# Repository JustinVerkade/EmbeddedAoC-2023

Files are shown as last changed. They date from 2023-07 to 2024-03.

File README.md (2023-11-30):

# Embedded-AoC "Yuki"<br />
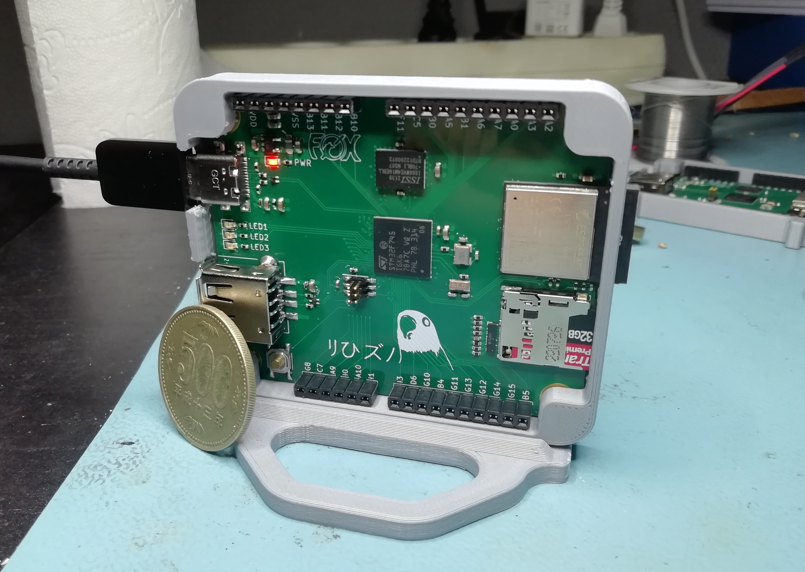
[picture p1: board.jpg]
EmbeddedAoC
<br />

## Todo<br />
-> Add ESP32 bootloader function in vcom user interface for remote programming.<br />
-> Add system check for ESP32.<br />

## Completed<br />
-> Added a malloc/calloc/clrmem functions to allocate memory from the SRAM block.<br />
-> Configured FMC and linker to include the external memory as SRAM block.<br />
-> Added vcom enable variable so the system can respond to being opend as port.<br />
-> Added intermediate usb layer as the transmit function failed when bizzy without feedback.<br />
-> f_debug function to log FatFs problems to vcom interface.<br />
-> Added system check for SD card.<br />
-> Added system check for SRAM memory.<br />
-> Added system structure for executing AoC puzzles.<br />

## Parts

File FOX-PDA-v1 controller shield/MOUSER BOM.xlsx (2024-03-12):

Name: | Description: | Price | Qty | Total | Link
THB001P | Joystick | €1.88 | 1 | €1.88 | https://nl.mouser.com/ProductDetail/CK/THB001P?qs=OlC7AqGiEDlMaVQ%2FEBrivA%3D%3D
150060AS75000 | LEDS 0805 | €0.14 | 3 | €0.42 | https://nl.mouser.com/ProductDetail/Wurth-Elektronik/150060AS75000?qs=d0WKAl%252BL4KbvMBYryeof0Q%3D%3D
CL21A106MQFNNNF | Capacitor 0805 10u | €0.09 | 3 | €0.28 | https://nl.mouser.com/ProductDetail/Samsung-Electro-Mechanics/CL21A106MQFNNNF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
CRCW08055K00JNTA | Resistor 0805 5k | €0.15 | 6 | €0.90 | https://nl.mouser.com/ProductDetail/Vishay-Dale/CRCW08055K00JNTA?qs=ypDtOmddc9yTg%252BhfBkNNHg%3D%3D
68001-206HLF | Header 6p male | €0.45 | 1 | €0.45 | https://nl.mouser.com/ProductDetail/Amphenol-FCI/68001-206HLF?qs=zh4O8xspOuwCLzyjXImWOg%3D%3D
68001-208HLF | Header 8p male | €0.69 | 1 | €0.69 | https://nl.mouser.com/ProductDetail/Amphenol-FCI/68001-208HLF?qs=p7Li5uGGkAoXsNrI4svk2w%3D%3D
68001-210HLF | Header 10p male | €0.67 | 2 | €1.33 | https://nl.mouser.com/ProductDetail/Amphenol-FCI/68001-210HLF?qs=QKvFUfBIyQKW08n2%252BQxlGA%3D%3D
 |  | Total | 17 | €5.96

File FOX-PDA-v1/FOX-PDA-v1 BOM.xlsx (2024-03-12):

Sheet: Sheet1
Name: | Description: | Price | Qty | Total | Link
STM32F745IGK6 | Microcontroller | €19.240 | 1 | €19.24 | https://nl.mouser.com/ProductDetail/STMicroelectronics/STM32F745IGK6?qs=k5OWtXsTJarJliH1%252Bru6hg%3D%3D
IS66WVE4M16EBLL-70BLI | PSRAM 64Mbit | €4.440 | 1 | €4.44 | https://nl.mouser.com/ProductDetail/ISSI/IS66WVE4M16EBLL-70BLI?qs=ULk7ZlyDR4cw9k0cpKJeQQ%3D%3D
ESP32-S2-MINI-1-N4 | ESP32 Wifi module | €2.050 | 1 | €2.05 | https://nl.mouser.com/ProductDetail/Espressif-Systems/ESP32-S2-MINI-1-N4
USB1046-GF-0190-L-B-A | USB-A connector | €0.714 | 1 | €0.71 | https://nl.mouser.com/ProductDetail/GCT/USB1046-GF-0190-L-B-A?qs=KUoIvG%2F9IlbZOJtEsn1unA%3D%3D
USB4110-GF-A | USB-C connector | €1.270 | 1 | €1.27 | https://nl.mouser.com/ProductDetail/GCT/USB4110-GF-A?qs=KUoIvG%2F9IlYiZvIXQjyJeA%3D%3D
MEM2080-00-128-00-A | uSD connector | €1.460 | 1 | €1.46 | https://nl.mouser.com/ProductDetail/GCT/MEM2080-00-128-00-A?qs=vvQtp7zwQdPJXzpf1SnYug%3D%3D
ADP2108AUJZ-3.3-R7 | regulator | €2.260 | 1 | €2.26 | https://nl.mouser.com/ProductDetail/Analog-Devices/ADP2108AUJZ-3.3-R7?qs=WIvQP4zGangwKS4DOjDn0A%3D%3D
TS18-5-25-SL-260-SMT-TR | Reset button | €0.179 | 1 | €0.18 | https://nl.mouser.com/ProductDetail/CUI-Devices/TS18-5-25-SL-260-SMT-TR?qs=tlsG%2FOw5FFh0yS4gYnfcwg%3D%3D
ECS-160-7-33B-CKL-TR | 16MHz crystal | €0.479 | 1 | €0.48 | https://nl.mouser.com/ProductDetail/ECS/ECS-160-7-33B-CKL-TR?qs=wd5RIQLrsJhEy%252BtlnvJYvQ%3D%3D
ECS-.327-12.5-34B-TR | 32.- KHz crystal | €0.649 | 1 | €0.65 | https://nl.mouser.com/ProductDetail/ECS/ECS-.327-12.5-34B-TR?qs=xCP1SmiXvZHPyAjhnmNtEw%3D%3D
LQM21PN1R0MC0D | Power inductor buck converter | €0.216 | 1 | €0.22 | https://nl.mouser.com/ProductDetail/Murata-Electronics/LQM21PN1R0MC0D?qs=%2F%252BYoplLUB5gbQdB9sWu6pw%3D%3D
TPD2EUSB30ADRTR | USB ESD diodes | €0.517 | 2 | €1.03 | https://nl.mouser.com/ProductDetail/Texas-Instruments/TPD2EUSB30ADRTR?qs=O1HRStiETCgOfMa6oTfOlg%3D%3D
ESD8708MUTAG | uSD ESD diodes | €0.639 | 1 | €0.64 | https://nl.mouser.com/ProductDetail/onsemi/ESD8708MUTAG?qs=%252B6g0mu59x7J1h3T%252BrbDk%252Bw%3D%3D
ESD9L5.0ST5G | 50V ESD diodes | €0.348 | 2 | €0.70 | https://nl.mouser.com/ProductDetail/onsemi/ESD9L5.0ST5G?qs=lq5%252BOP7PS0%252BtbEEODUxZiA%3D%3D
SLW-108-01-T-S | IO header 8p | €1.230 | 1 | €1.23 | https://nl.mouser.com/ProductDetail/Samtec/SLW-108-01-T-S?qs=rU5fayqh%252BE3vM7KKJPKLBQ%3D%3D
SLW-110-01-T-S | IO header 10p | €1.160 | 2 | €2.32 | https://nl.mouser.com/ProductDetail/Samtec/SLW-110-01-T-S?qs=WqbWUrltBn0VpUHXVPrl6A%3D%3D
SLW-106-01-T-S | IO header 6p | €0.846 | 1 | €0.85 | https://nl.mouser.com/ProductDetail/Samtec/SLW-106-01-T-S?qs=92ilVni64gwgeQzrY9annQ%3D%3D
20021121-00006T4LF | Programming header | €0.564 | 1 | €0.56 | https://nl.mouser.com/ProductDetail/Amphenol-FCI/20021121-00006T4LF?qs=oJs1R%252BxK6kTRYpFukouk8Q%3D%3D
150060AS75000 | LEDS 0805 | €0.141 | 4 | €0.56 | https://nl.mouser.com/ProductDetail/Wurth-Elektronik/150060AS75000?qs=d0WKAl%252BL4KbvMBYryeof0Q%3D%3D
MMZ1005S121HT000 | Ferrite bead | €0.094 | 1 | €0.09 | https://nl.mouser.com/ProductDetail/TDK/MMZ1005S121HT000?qs=1mbolxNpo8cEy9%252BGeuXdTw%3D%3D
CRCW040222R0JNEDC | Resistor 0402 22R | €0.094 | 4 | €0.38 | https://nl.mouser.com/ProductDetail/Vishay-Dale/CRCW040222R0JNEDC?qs=E3Y5ESvWgWOe0pjbCFgU3w%3D%3D
CR0402-FX-2201GLF | Resistor 0402 2.2K | €0.094 | 3 | €0.28 | https://nl.mouser.com/ProductDetail/Bourns/CR0402-FX-2201GLF?qs=JflQ4L8so%2FvNNp%252Bb%2FjYwIg%3D%3D
RT0402FRD0710KL | Resistor 0402 10K | €0.127 | 10 | €1.27 | https://nl.mouser.com/ProductDetail/YAGEO/RT0402FRD0710KL?qs=9h0bZHM%2F3zLluUCJgNukFQ%3D%3D
CRCW040247R0FKEDC | Resistor 0402 47R | €0.094 | 2 | €0.19 | https://nl.mouser.com/ProductDetail/Vishay-Dale/CRCW040247R0FKEDC?qs=E3Y5ESvWgWOUCyfYkhtspA%3D%3D
RT0402FRD071KL | Resistor 0402 1K | €0.160 | 4 | €0.64 | https://nl.mouser.com/ProductDetail/YAGEO/RT0402FRD071KL?qs=ABvmyp11KkjmRlIyrfVQ%252BQ%3D%3D
AC0402JR-075K1L | Resistor 0402 5.1K | €0.094 | 2 | €0.19 | https://nl.mouser.com/ProductDetail/YAGEO/AC0402JR-075K1L?qs=ygRr%2Ftkhtev1AbJgasJMAQ%3D%3D
04026D104KAT2A | Capacitor 0402 100n | €0.010 | 21 | €0.21 | https://nl.mouser.com/ProductDetail/Kyocera-AVX/04026D104KAT2A?qs=LLG2yGGJ5NhILwMziGI8Xg%3D%3D
CL10A225KO8NNNC | Capacitor 0603 2.2u | €0.094 | 9 | €0.85 | https://nl.mouser.com/ProductDetail/Samsung-Electro-Mechanics/CL10A225KO8NNNC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
GRM153R60J225ME95D | Capacitor 0402 2.2u | €0.094 | 2 | €0.19 | https://nl.mouser.com/ProductDetail/Murata-Electronics/GRM153R60J225ME95D?qs=bR4DfHEEY0uHJr0etQOHow%3D%3D
GRM1555C1H100JA01J | Capacitor 0402 10p | €0.094 | 2 | €0.19 | https://nl.mouser.com/ProductDetail/Murata-Electronics/GRM1555C1H100JA01J?qs=ouTquLLW2S5kS%252BYeQbW79A%3D%3D
GRM1555C1H180JA01D | Capacitor 0402 18p | €0.094 | 2 | €0.19 | https://nl.mouser.com/ProductDetail/Murata-Electronics/GRM1555C1H180JA01D?qs=mRkWMvdT7ZKEkI5QPHEfww%3D%3D
06036D475KAT4A | Capacitor 0603 4.7u | €0.122 | 1 | €0.12 | https://nl.mouser.com/ProductDetail/KYOCERA-AVX/06036D475KAT4A?qs=Q5Oar%2FnnWZYQ5N3tKG3HJg%3D%3D
06036D106MAT2A | Capacitor 0603 10u | €0.169 | 1 | €0.17 | https://nl.mouser.com/ProductDetail/Kyocera-AVX/06036D106MAT2A?qs=SnLCPPi%2FUkQWQ97wPZ%2F8XA%3D%3D
 |  | Total | 89 | €45.80
Additional parts
Name: | Description: | Price | Qty | Total | Link
20021311-00006T4LF | Programming header host | €0.686 | 1 | €0.69 | https://nl.mouser.com/ProductDetail/Amphenol-FCI/20021311-00006T4LF?qs=oJs1R%252BxK6kSLec%2FNAKmHQA%3D%3D
10129378-906001BLF | Programming header target | €0.160 | 1 | €0.16 | https://nl.mouser.com/ProductDetail/Amphenol-FCI/10129378-906001BLF?qs=0lQeLiL1qybdgsDy2F9d0g%3D%3D

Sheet: Sheet3
Name: | Description: | Price | Qty | Total | Link
STM32F745IGK6 | Microcontroller | €19.24 | 5 | €96.20 | https://nl.mouser.com/ProductDetail/STMicroelectronics/STM32F745IGK6?qs=k5OWtXsTJarJliH1%252Bru6hg%3D%3D
IS66WVE4M16EBLL-70BLI | PSRAM 64Mbit | €4.44 | 5 | €22.20 | https://nl.mouser.com/ProductDetail/ISSI/IS66WVE4M16EBLL-70BLI?qs=ULk7ZlyDR4cw9k0cpKJeQQ%3D%3D
ESP32-S2-MINI-1-N4 | ESP32 Wifi module | €2.05 | 5 | €10.25 | https://nl.mouser.com/ProductDetail/Espressif-Systems/ESP32-S2-MINI-1-N4
USB1046-GF-0190-L-B-A | USB-A connector | €0.71 | 5 | €3.57 | https://nl.mouser.com/ProductDetail/GCT/USB1046-GF-0190-L-B-A?qs=KUoIvG%2F9IlbZOJtEsn1unA%3D%3D
USB4110-GF-A | USB-C connector | €1.27 | 5 | €6.35 | https://nl.mouser.com/ProductDetail/GCT/USB4110-GF-A?qs=KUoIvG%2F9IlYiZvIXQjyJeA%3D%3D
MEM2080-00-128-00-A | uSD connector | €1.46 | 5 | €7.30 | https://nl.mouser.com/ProductDetail/GCT/MEM2080-00-128-00-A?qs=vvQtp7zwQdPJXzpf1SnYug%3D%3D
ADP2108AUJZ-3.3-R7 | regulator | €2.26 | 5 | €11.30 | https://nl.mouser.com/ProductDetail/Analog-Devices/ADP2108AUJZ-3.3-R7?qs=WIvQP4zGangwKS4DOjDn0A%3D%3D
TS18-5-25-SL-260-SMT-TR | Reset button | €0.18 | 5 | €0.90 | https://nl.mouser.com/ProductDetail/CUI-Devices/TS18-5-25-SL-260-SMT-TR?qs=tlsG%2FOw5FFh0yS4gYnfcwg%3D%3D
ECS-160-7-33B-CKL-TR | 16MHz crystal | €0.52 | 5 | €2.58 | https://nl.mouser.com/ProductDetail/ECS/ECS-160-7-33B-CKL-TR?qs=wd5RIQLrsJhEy%252BtlnvJYvQ%3D%3D
ECS-.327-12.5-34B-TR | 32.- KHz crystal | €0.65 | 5 | €3.25 | https://nl.mouser.com/ProductDetail/ECS/ECS-.327-12.5-34B-TR?qs=xCP1SmiXvZHPyAjhnmNtEw%3D%3D
LQM21PN1R0MC0D | Power inductor buck converter | €0.22 | 5 | €1.08 | https://nl.mouser.com/ProductDetail/Murata-Electronics/LQM21PN1R0MC0D?qs=%2F%252BYoplLUB5gbQdB9sWu6pw%3D%3D
TPD2EUSB30ADRTR | USB ESD diodes | €0.52 | 10 | €5.17 | https://nl.mouser.com/ProductDetail/Texas-Instruments/TPD2EUSB30ADRTR?qs=O1HRStiETCgOfMa6oTfOlg%3D%3D
ESD8708MUTAG | uSD ESD diodes | €0.64 | 5 | €3.20 | https://nl.mouser.com/ProductDetail/onsemi/ESD8708MUTAG?qs=%252B6g0mu59x7J1h3T%252BrbDk%252Bw%3D%3D
ESD9L5.0ST5G | 50V ESD diodes | €0.35 | 10 | €3.48 | https://nl.mouser.com/ProductDetail/onsemi/ESD9L5.0ST5G?qs=lq5%252BOP7PS0%252BtbEEODUxZiA%3D%3D
SLW-108-01-T-S | IO header 8p | €1.23 | 5 | €6.15 | https://nl.mouser.com/ProductDetail/Samtec/SLW-108-01-T-S?qs=rU5fayqh%252BE3vM7KKJPKLBQ%3D%3D
SLW-110-01-T-S | IO header 10p | €1.16 | 10 | €11.60 | https://nl.mouser.com/ProductDetail/Samtec/SLW-110-01-T-S?qs=WqbWUrltBn0VpUHXVPrl6A%3D%3D
SLW-106-01-T-S | IO header 6p | €0.85 | 5 | €4.23 | https://nl.mouser.com/ProductDetail/Samtec/SLW-106-01-T-S?qs=92ilVni64gwgeQzrY9annQ%3D%3D
20021121-00006T4LF | Programming header | €0.56 | 5 | €2.82 | https://nl.mouser.com/ProductDetail/Amphenol-FCI/20021121-00006T4LF?qs=oJs1R%252BxK6kTRYpFukouk8Q%3D%3D
150060AS75000 | LEDS 0805 | €0.14 | 20 | €2.82 | https://nl.mouser.com/ProductDetail/Wurth-Elektronik/150060AS75000?qs=d0WKAl%252BL4KbvMBYryeof0Q%3D%3D
MMZ1005S121HT000 | Ferrite bead | €0.09 | 5 | €0.00 | https://nl.mouser.com/ProductDetail/TDK/MMZ1005S121HT000?qs=1mbolxNpo8cEy9%252BGeuXdTw%3D%3D
CRCW040222R0JNEDC | Resistor 0402 22R | €0.09 | 20 | €1.88 | https://nl.mouser.com/ProductDetail/Vishay-Dale/CRCW040222R0JNEDC?qs=E3Y5ESvWgWOe0pjbCFgU3w%3D%3D
CR0402-FX-2201GLF | Resistor 0402 2.2K | €0.09 | 15 | €1.41 | https://nl.mouser.com/ProductDetail/Bourns/CR0402-FX-2201GLF?qs=JflQ4L8so%2FvNNp%252Bb%2FjYwIg%3D%3D
RT0402FRD0710KL | Resistor 0402 10K | €0.09 | 50 | €4.70 | https://nl.mouser.com/ProductDetail/YAGEO/RT0402FRD0710KL?qs=9h0bZHM%2F3zLluUCJgNukFQ%3D%3D
CRCW040247R0FKEDC | Resistor 0402 47R | €0.09 | 10 | €0.94 | https://nl.mouser.com/ProductDetail/Vishay-Dale/CRCW040247R0FKEDC?qs=E3Y5ESvWgWOUCyfYkhtspA%3D%3D
RT0402FRD071KL | Resistor 0402 1K | €0.09 | 20 | €1.88 | https://nl.mouser.com/ProductDetail/YAGEO/RT0402FRD071KL?qs=ABvmyp11KkjmRlIyrfVQ%252BQ%3D%3D
AC0402JR-075K1L | Resistor 0402 5.1K | €0.09 | 10 | €0.94 | https://nl.mouser.com/ProductDetail/YAGEO/AC0402JR-075K1L?qs=ygRr%2Ftkhtev1AbJgasJMAQ%3D%3D
04026D104KAT2A | Capacitor 0402 100n | €0.09 | 105 | €9.87 | https://nl.mouser.com/ProductDetail/Kyocera-AVX/04026D104KAT2A?qs=LLG2yGGJ5NhILwMziGI8Xg%3D%3D
CL10A225KO8NNNC | Capacitor 0603 2.2u | €0.09 | 45 | €4.23 | https://nl.mouser.com/ProductDetail/Samsung-Electro-Mechanics/CL10A225KO8NNNC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
GRM153R60J225ME95D | Capacitor 0402 2.2u | €0.09 | 10 | €0.94 | https://nl.mouser.com/ProductDetail/Murata-Electronics/GRM153R60J225ME95D?qs=bR4DfHEEY0uHJr0etQOHow%3D%3D
GRM1555C1H100JA01J | Capacitor 0402 10p | €0.09 | 10 | €0.94 | https://nl.mouser.com/ProductDetail/Murata-Electronics/GRM1555C1H100JA01J?qs=ouTquLLW2S5kS%252BYeQbW79A%3D%3D
GRM1555C1H180JA01D | Capacitor 0402 18p | €0.09 | 10 | €0.94 | https://nl.mouser.com/ProductDetail/Murata-Electronics/GRM1555C1H180JA01D?qs=mRkWMvdT7ZKEkI5QPHEfww%3D%3D
06036D475KAT4A | Capacitor 0603 4.7u | €0.12 | 5 | €0.61 | https://nl.mouser.com/ProductDetail/KYOCERA-AVX/06036D475KAT4A?qs=Q5Oar%2FnnWZYQ5N3tKG3HJg%3D%3D
06036D106MAT2A | Capacitor 0603 10u | €0.17 | 5 | €0.85 | https://nl.mouser.com/ProductDetail/Kyocera-AVX/06036D106MAT2A?qs=SnLCPPi%2FUkQWQ97wPZ%2F8XA%3D%3D
 |  | Total | 445 | €233.72

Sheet: Sheet2
STM32F745IGK6 | 1
IS66WVE4M16EBLL-70BLI | 1
ESP32-S2-MINI-1-N4 | 1
USB1046-GF-0190-L-B-A | 1
USB4110-GF-A | 1
MEM2080-00-128-00-A | 1
ADP2108AUJZ-3.3-R7 | 1
TS18-5-25-SL-260-SMT-TR | 1
ECS-160-7-33B-CKL-TR | 1
ECS-.327-12.5-34B-TR | 1
LQM21PN1R0MC0D | 1
TPD2EUSB30ADRTR | 2
ESD8708MUTAG | 1
ESD9L5.0ST5G | 2
SLW-108-01-T-S | 1
SLW-110-01-T-S | 2
SLW-106-01-T-S | 1
20021121-00006T4LF | 1
150060AS75000 | 4
MMZ1005S121HT000 | 1
CRCW040222R0JNEDC | 4
CR0402-FX-2201GLF | 3
RT0402FRD0710KL | 10
CRCW040247R0FKEDC | 2
RT0402FRD071KL | 4
AC0402JR-075K1L | 2
04026D104KAT2A | 21
CL10A225KO8NNNC | 9
GRM153R60J225ME95D | 2
GRM1555C1H100JA01J | 2
GRM1555C1H180JA01D | 2
06036D475KAT4A | 1
06036D106MAT2A | 1

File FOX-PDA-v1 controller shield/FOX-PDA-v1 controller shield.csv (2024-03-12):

Source: | C:\Users\J.Verkade\OneDrive\KiCad\Projects\FOX-PDA-v1 controller shield\FOX-PDA-v1 controller shield\FOX-PDA-v1 controller shield.kicad_sch
Date: | 21-6-2023 20:30:07
Tool: | Eeschema (6.0.10)
Generator: | C:\Program Files\KiCad\6.0\bin\scripting\plugins/bom_csv_grouped_by_value_with_fp.py
Component Count: | 21
Ref | Qnty | Value | Cmp name | Footprint | Description | Vendor
C1, C2, C3, | 3 | 10u | C_Small | Capacitor_SMD:C_0805_2012Metric | Unpolarized capacitor, small symbol
H1, H2, H3, H4, | 4 | MountingHole_Pad | MountingHole_Pad | MountingHole:MountingHole_3.2mm_M3_Pad_Via | Mounting Hole with connection
J1, | 1 | SLW-108-01-T-S | SLW-108-01-T-S | SamacSys_Parts:SLW-108-01-X-S | 8 Position, .100&quot; Tiger Buy&trade; Low Profile Socket Strip, Single-Row
J2, J3, | 2 | SLW-110-01-T-S | SLW-110-01-T-S | SamacSys_Parts:SLW-110-01-X-S | 10 Position, .100&quot; Tiger Buy&trade; Low Profile Socket Strip, Single-Row
J4, | 1 | SLW-106-01-T-S | SLW-106-01-T-S | SamacSys_Parts:SLW-106-01-X-S | 6 Position, .100&quot; Tiger Buy&trade; Low Profile Socket Strip, Single-Row
LED1, LED2, LED3, | 3 | 150060AS75000 | 150060AS75000 | SamacSys_Parts:LEDC1608X80N | 2.4 V Amber LED 1608 (0603) SMD, Wurth Elektronik WL-SMCW 150060AS75000
R1, R2, R3, R4, R5, R6, | 6 | 5k | R_Small | Resistor_SMD:R_0805_2012Metric | Resistor, small symbol
S1, | 1 | THB001P | THB001P | SamacSys_Parts:THB001P | THUMBSTICK, 0.05A, 12VDC, 2 AXIS, PCB; No. of Axes:2; Track Resistance:10kohm; Supply Voltage Max:-; No. of Switch Positions:-; Contact Current AC Max:-; Contact Voltage AC Max:50V; Rotation Electrical Angle:36

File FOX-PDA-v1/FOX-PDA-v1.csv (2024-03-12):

Source: | C:\Users\J.Verkade\OneDrive\KiCad\Projects\FOX-PDA-v1\FOX-PDA-v1\FOX-PDA-v1.kicad_sch
Date: | 21-6-2023 20:10:43
Tool: | Eeschema (6.0.10)
Generator: | C:\Program Files\KiCad\6.0\bin\scripting\plugins/bom_csv_grouped_by_value_with_fp.py
Component Count: | 93
Ref | Qnty | Value | Cmp name | Footprint | Description | Vendor
C1, C2, C3, C4, C5, C6, C7, C8, C9, C10, C13, C14, C15, C16, C17, C21, C28, C29, C30, C35, C38, | 21 | 100n | C_Small | Capacitor_SMD:C_0402_1005Metric | Unpolarized capacitor, small symbol
C18, C19, | 2 | 2.2u | C_Small | Capacitor_SMD:C_0402_1005Metric | Unpolarized capacitor, small symbol
C20, C22, C23, C24, C25, C26, C27, C36, C37, | 9 | 2.2u | C_Small | Capacitor_SMD:C_0603_1608Metric | Unpolarized capacitor, small symbol
C31, C32, | 2 | 10p | C_Small | Capacitor_SMD:C_0402_1005Metric | Unpolarized capacitor, small symbol
C33, C34, | 2 | 18p | C_Small | Capacitor_SMD:C_0402_1005Metric | Unpolarized capacitor, small symbol
C39, | 1 | 4.7u | C_Small | Capacitor_SMD:C_0603_1608Metric | Unpolarized capacitor, small symbol
C40, | 1 | 10u | C_Small | Capacitor_SMD:C_0603_1608Metric | Unpolarized capacitor, small symbol
D1, | 1 | ESD8708MUTAG | ESD8708MUTAG | SamacSys_Parts:ESD8708MUTAG | ESD Suppressors / TVS Diodes 8 CHANNEL, 3.3 V UNIDIREC
D2, D3, | 2 | ESD9101P2T5G | ESD9101P2T5G | SamacSys_Parts:SODFL1006X40N | Low Capacitance ESD Protection Diodes for High Speed Data Lines
FB1, | 1 | MMZ1005S121HT000 | MMZ1005S121HT000 | SamacSys_Parts:BEADC1005X55N | Ferrite Beads 0402 120ohms 25% General Signal Line
H1, H2, H3, H4, | 4 | MountingHole_Pad | MountingHole_Pad | MountingHole:MountingHole_3.2mm_M3_Pad_Via | Mounting Hole with connection
IC1, | 1 | STM32F745IGK6 | STM32F745IGK6 | SamacSys_Parts:BGA201C65P15X15_1000X1000X60 | High-performance and DSP with FPU, Arm Cortex-M7 MCU with 1 Mbyte of Flash memory, 216 MHz CPU, Art Accelerator, L1 cache, SDRAM
IC2, | 1 | IS66WVE4M16EBLL-70BLI | IS66WVE4M16EBLL-70BLI | SamacSys_Parts:BGA48C75P6X8_600X800X120 | SRAM 64Mb,Pseudo SRAM,Asynch/Page, 4M x 16,70ns,VDD 2.7V 3.6V, VDDQ 2.7V 3.6V,48 Ball BGA (6x8 mm), RoHS
IC3, | 1 | ESP32-S2-MINI-1-N4 | ESP32-S2-MINI-1-N4 | SamacSys_Parts:ESP32S2MINI1N4 | SMD MODULE W/PCB ANTENNA
IC4, IC5, | 2 | TPD2EUSB30ADRTR | TPD2EUSB30ADRTR | SamacSys_Parts:SOT35P100X50-3N | 2-Channel ESD/Surge Solution for High-Speed Low-Voltage Interface
IC6, | 1 | ADP2108AUJZ-3.3-R7 | ADP2108AUJZ-3.3-R7 | SamacSys_Parts:SOT95P280X100-5N | DC-DC 3.3V 600mA 3MHz Step-Down TSOT5 Analog Devices ADP2108AUJZ-3.3-R7, Single Linear Voltage Regulator, 600mA 3.3 V, +/-2 %, +/-2.5 %, 5-Pin TSOT
J1, | 1 | USB1046-GF-0190-L-B-A | USB1046-GF-0190-L-B-A | SamacSys_Parts:USB1046GF0190LBA | USB Connectors USB A Skt, Top Mount, SMT, R/A, GF, Black, With 1.9mm shell stake, T&R
J2, | 1 | USB4110-GF-A | USB4110-GF-A | SamacSys_Parts:USB4110GFA | CONN USB 2.0 TYPE-C R/A SMT
J3, | 1 | SLW-108-01-T-S | SLW-108-01-T-S | SamacSys_Parts:SLW-108-01-X-S | 8 Position, .100&quot; Tiger Buy&trade; Low Profile Socket Strip, Single-Row
J4, | 1 | 20021121-00006T4LF | 20021121-00006T4LF | SamacSys_Parts:HUSSP6W41P127_2X3_381X343X440P | Minitek127, Board to Board connector, Unshrouded vertical header, Surface Mount, Double Row, 6Positions, 1.27mm (0.5inch) pitch.
J5, J6, | 2 | SLW-110-01-T-S | SLW-110-01-T-S | SamacSys_Parts:SLW-110-01-X-S | 10 Position, .100&quot; Tiger Buy&trade; Low Profile Socket Strip, Single-Row
J7, | 1 | SLW-106-01-T-S | SLW-106-01-T-S | SamacSys_Parts:SLW-106-01-X-S | 6 Position, .100&quot; Tiger Buy&trade; Low Profile Socket Strip, Single-Row
J8, | 1 | MEM2080-00-128-00-A | MEM2080-00-128-00-A | SamacSys_Parts:MEM20800012800A | Memory Card Connectors Micro SD, Push Push, SMT, Card Entry Normal, 1.28 mm profile
L1, | 1 | LQM21PN1R0MC0D | LQM21PN1R0MC0D | SamacSys_Parts:LQM21PN1R0MC0D | LQM21PN_C0 Series Inductor 1.0uH +/-20% 0805 (2012)
LED1, LED2, LED3, LED4, | 4 | 150060AS75000 | 150060AS75000 | SamacSys_Parts:LEDC1608X80N | 2.4 V Amber LED 1608 (0603) SMD, Wurth Elektronik WL-SMCW 150060AS75000
R1, R2, R3, R4, | 4 | 22 | R_Small | Resistor_SMD:R_0402_1005Metric | Resistor, small symbol
R5, R6, | 2 | 5K1 | R_Small | Resistor_SMD:R_0402_1005Metric | Resistor, small symbol
R7, R10, R11, | 3 | 2.2k | R_Small | Resistor_SMD:R_0402_1005Metric | Resistor, small symbol
R8, R9, R12, R13, R14, R15, R16, R17, R18, R19, | 10 | 10k | R_Small | Resistor_SMD:R_0402_1005Metric | Resistor, small symbol
R20, R21, | 2 | 47 | R_Small | Resistor_SMD:R_0402_1005Metric | Resistor, small symbol
R22, R23, R24, R25, | 4 | 1k | R_Small | Resistor_SMD:R_0402_1005Metric | Resistor, small symbol
S1, | 1 | TS18-5-25-SL-260-SMT-TR | TS18-5-25-SL-260-SMT-TR | SamacSys_Parts:TS18525SL260SMTTR | TACTILE SWITCH 5 X 5 MM, 2.5 MM ACTUATOR HEIGHT 0.05A @ 12VDC Surface Mount -30C ~ 80C
Y1, | 1 | ECS-160-7-33B-CKL-TR | ECS-160-7-33B-CKL-TR | SamacSys_Parts:ECS160733BCKLTR | CRYSTAL 16MHZ 7PF SMD
Y2, | 1 | ECS-.327-12.5-34S-TR9 | ECS-.327-12.5-34S-TR9 | SamacSys_Parts:ECS32712534STR9 | Crystals 32.768 KHz 12.5 pF +/-20 ppm ECX-34S -40 - +125C 3215 RoHS Compliant

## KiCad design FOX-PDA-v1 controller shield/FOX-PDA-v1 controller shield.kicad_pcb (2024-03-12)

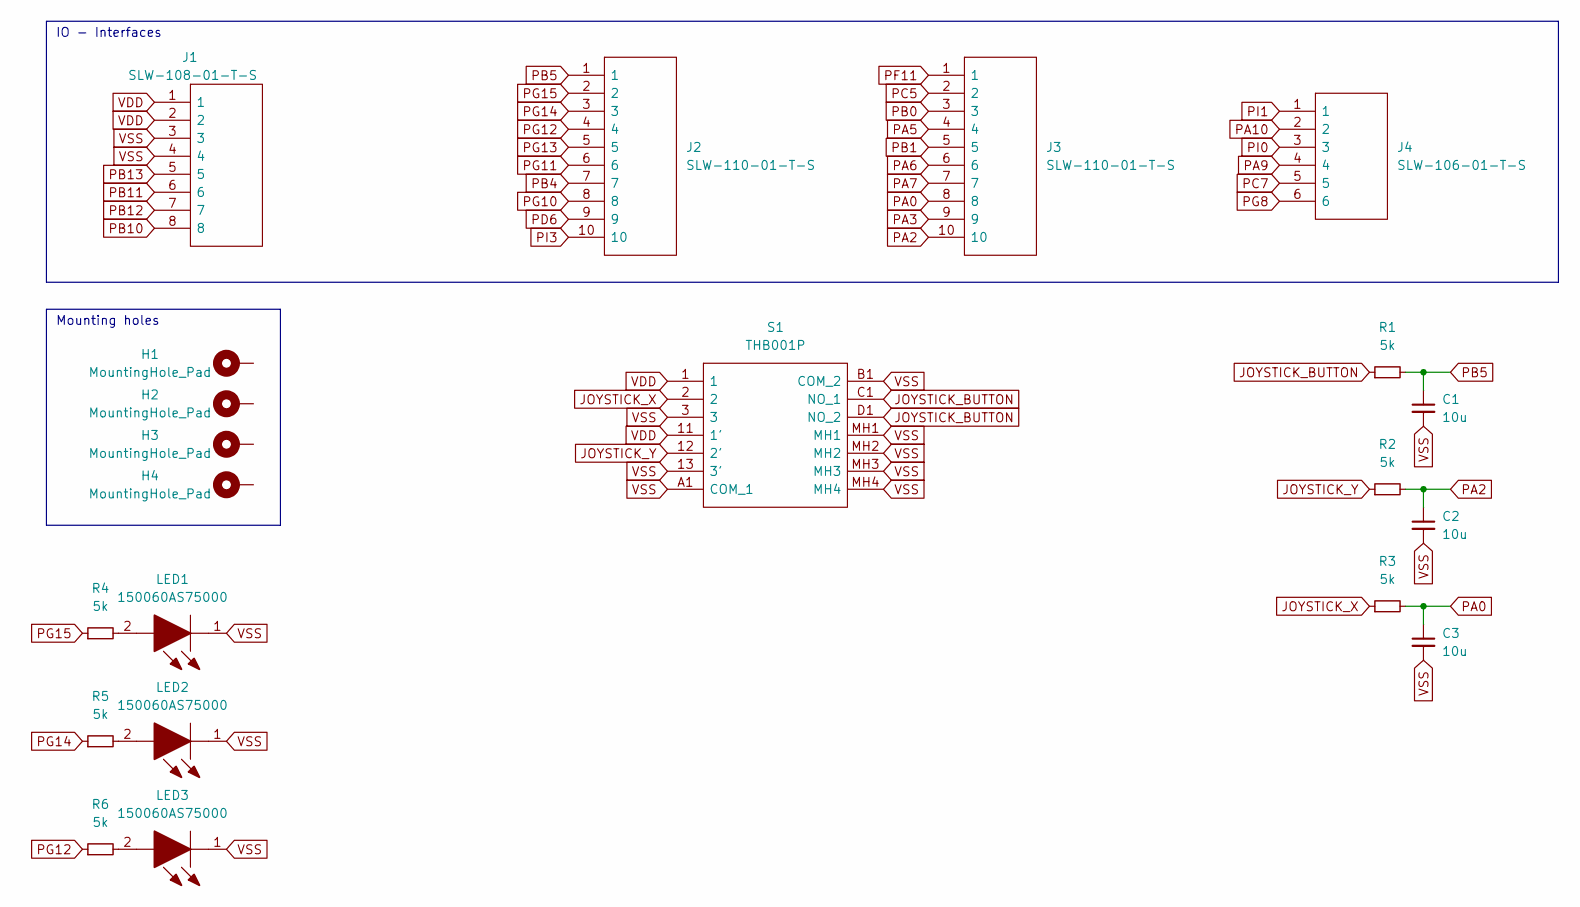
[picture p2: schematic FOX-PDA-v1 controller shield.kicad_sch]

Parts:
C1, C2, C3: 10u; C_0805_2012Metric
H1, H2, H3, H4: MountingHole_Pad; MountingHole_3.2mm_M3_Pad_Via
J1: SLW-108-01-T-S; SLW-108-01-X-S; Mouser Part Number 200-SLW10801TS
J2, J3: SLW-110-01-T-S; SLW-110-01-X-S; Mouser Part Number 200-SLW11001TS
J4: SLW-106-01-T-S; SLW-106-01-X-S; Mouser Part Number 200-SLW10601TS
LED1, LED2, LED3: 150060AS75000; LEDC1608X80N; Mouser Part Number 710-150060AS75000
R1, R2, R3, R4, R5, R6: 5k; R_0805_2012Metric
S1: THB001P; Mouser Part Number 611-THB001P

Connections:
JOYSTICK_BUTTON: R1.1, S1.C1 (NO_1), S1.D1 (NO_2)
JOYSTICK_X: R3.1, S1.2
JOYSTICK_Y: R2.1, S1.12 (2')
unnamed: LED1.2, R4.2
unnamed: LED2.2, R5.2
unnamed: LED3.2, R6.2
PA0: C3.1, J3.8, R3.2
PA2: C2.1, J3.10, R2.2
PA3: J3.9
PA5: J3.4
PA6: J3.6
PA7: J3.7
PA9: J4.4
PA10: J4.2
PB0: J3.3
PB1: J3.5
PB4: J2.7
PB5: C1.1, J2.1, R1.2
PB10: J1.8
PB11: J1.6
PB12: J1.7
PB13: J1.5
PC5: J3.2
PC7: J4.5
PD6: J2.9
PF11: J3.1
PG8: J4.6
PG10: J2.8
PG11: J2.6
PG12: J2.4, R6.1
PG13: J2.5
PG14: J2.3, R5.1
PG15: J2.2, R4.1
PI0: J4.3
PI1: J4.1
PI3: J2.10
VDD: J1.1, J1.2, S1.1, S1.11 (1')
VSS: C1.2, C2.2, C3.2, J1.3, J1.4, LED1.1, LED2.1, LED3.1, S1.3, S1.13 (3'), S1.A1 (COM_1), S1.B1 (COM_2), S1.MH1, S1.MH2, S1.MH3, S1.MH4

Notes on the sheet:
IO - Interfaces
Mounting holes

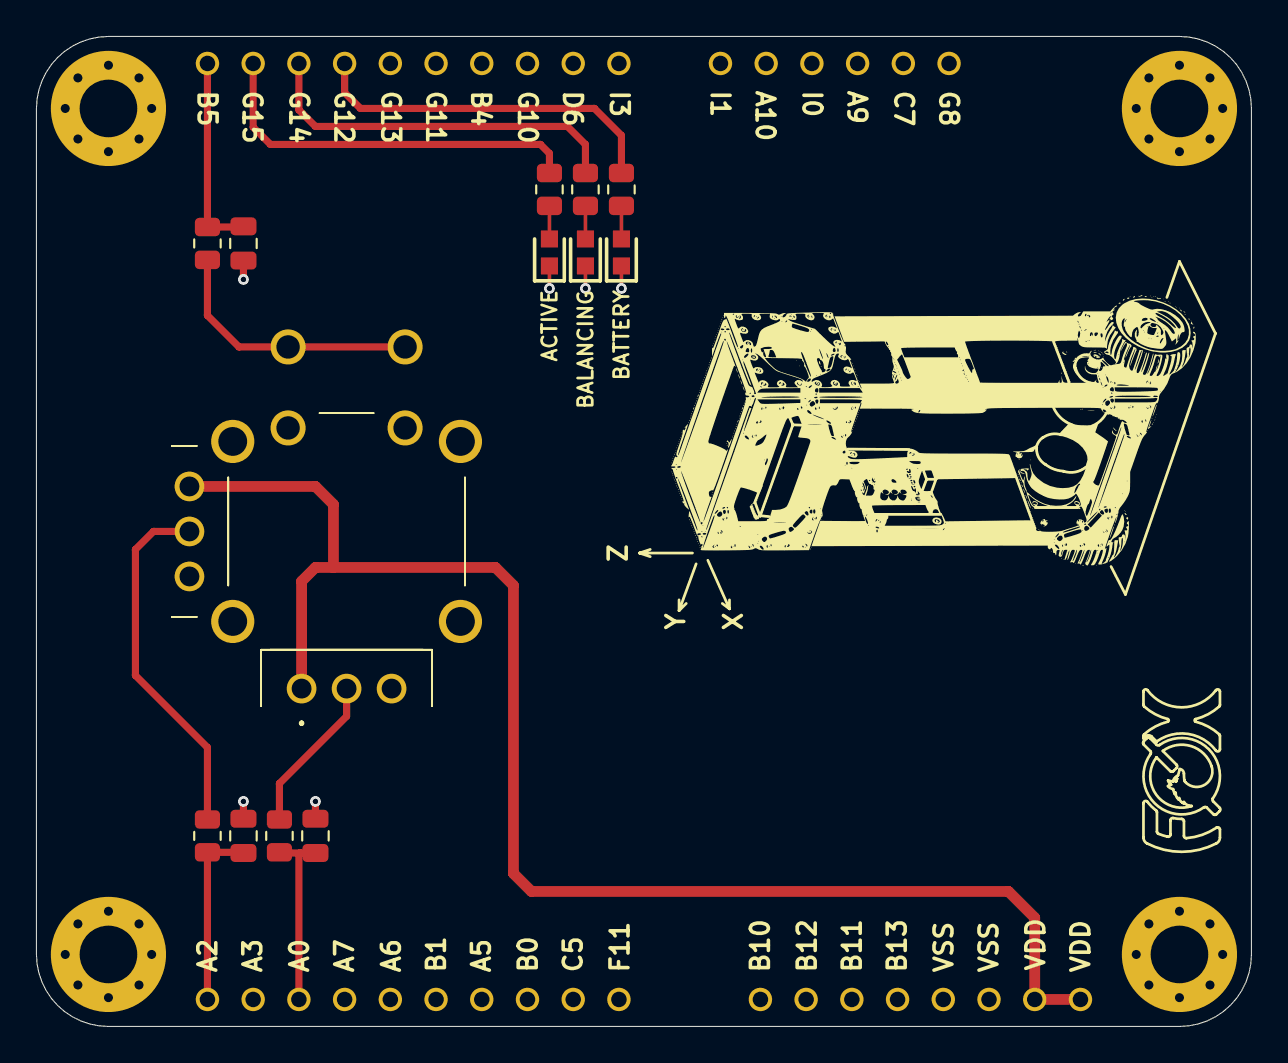
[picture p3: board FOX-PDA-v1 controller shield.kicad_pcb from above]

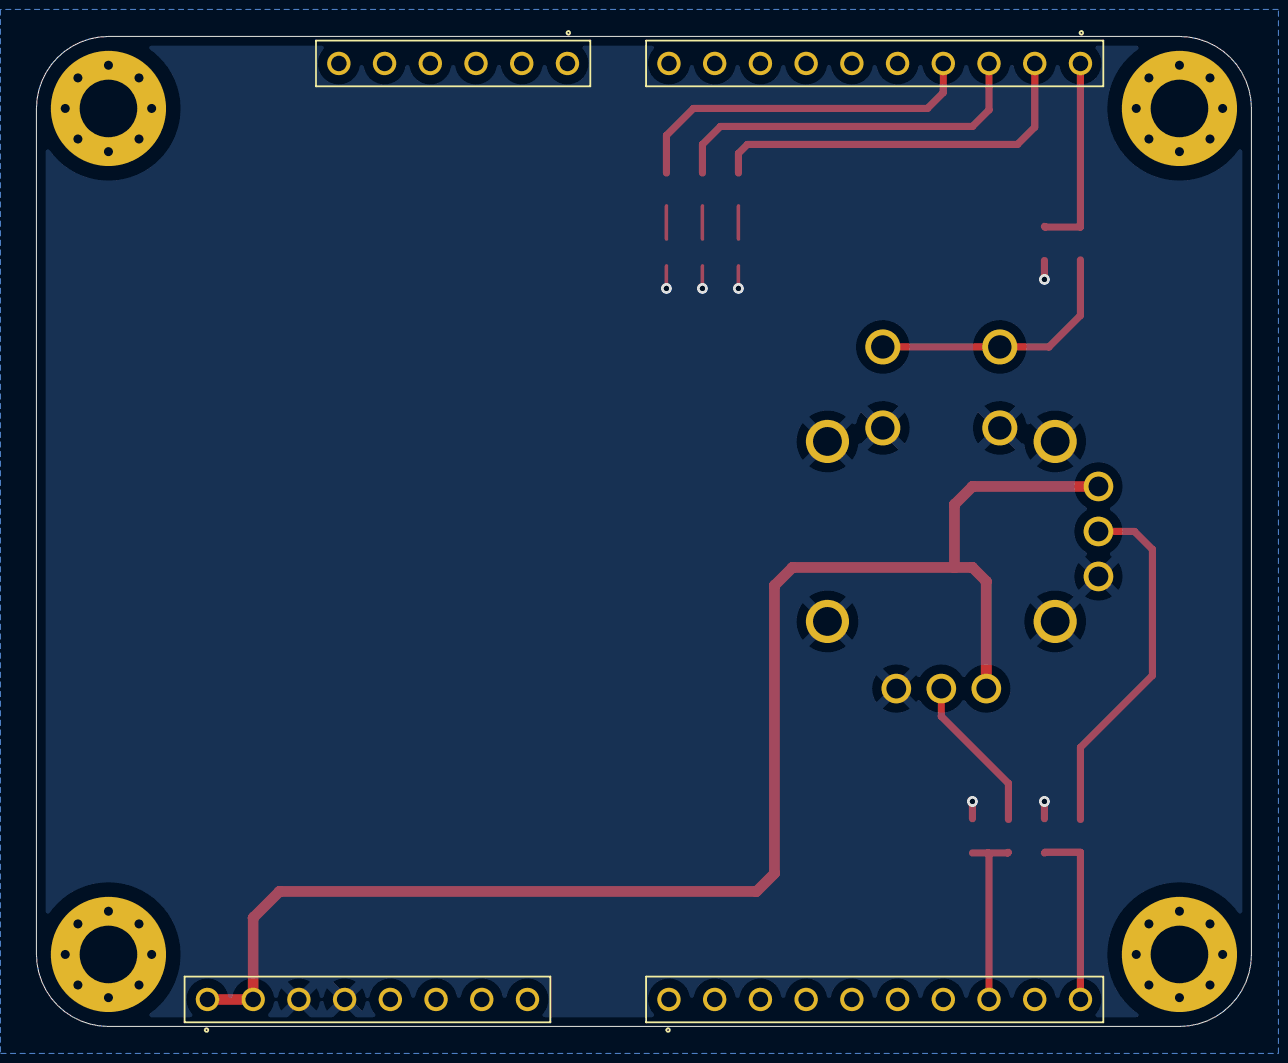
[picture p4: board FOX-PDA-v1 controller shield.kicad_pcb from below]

Board: 2 copper layers, 67.5 x 55.0 mm, 21 parts (4 on the bottom side), 14 nets.

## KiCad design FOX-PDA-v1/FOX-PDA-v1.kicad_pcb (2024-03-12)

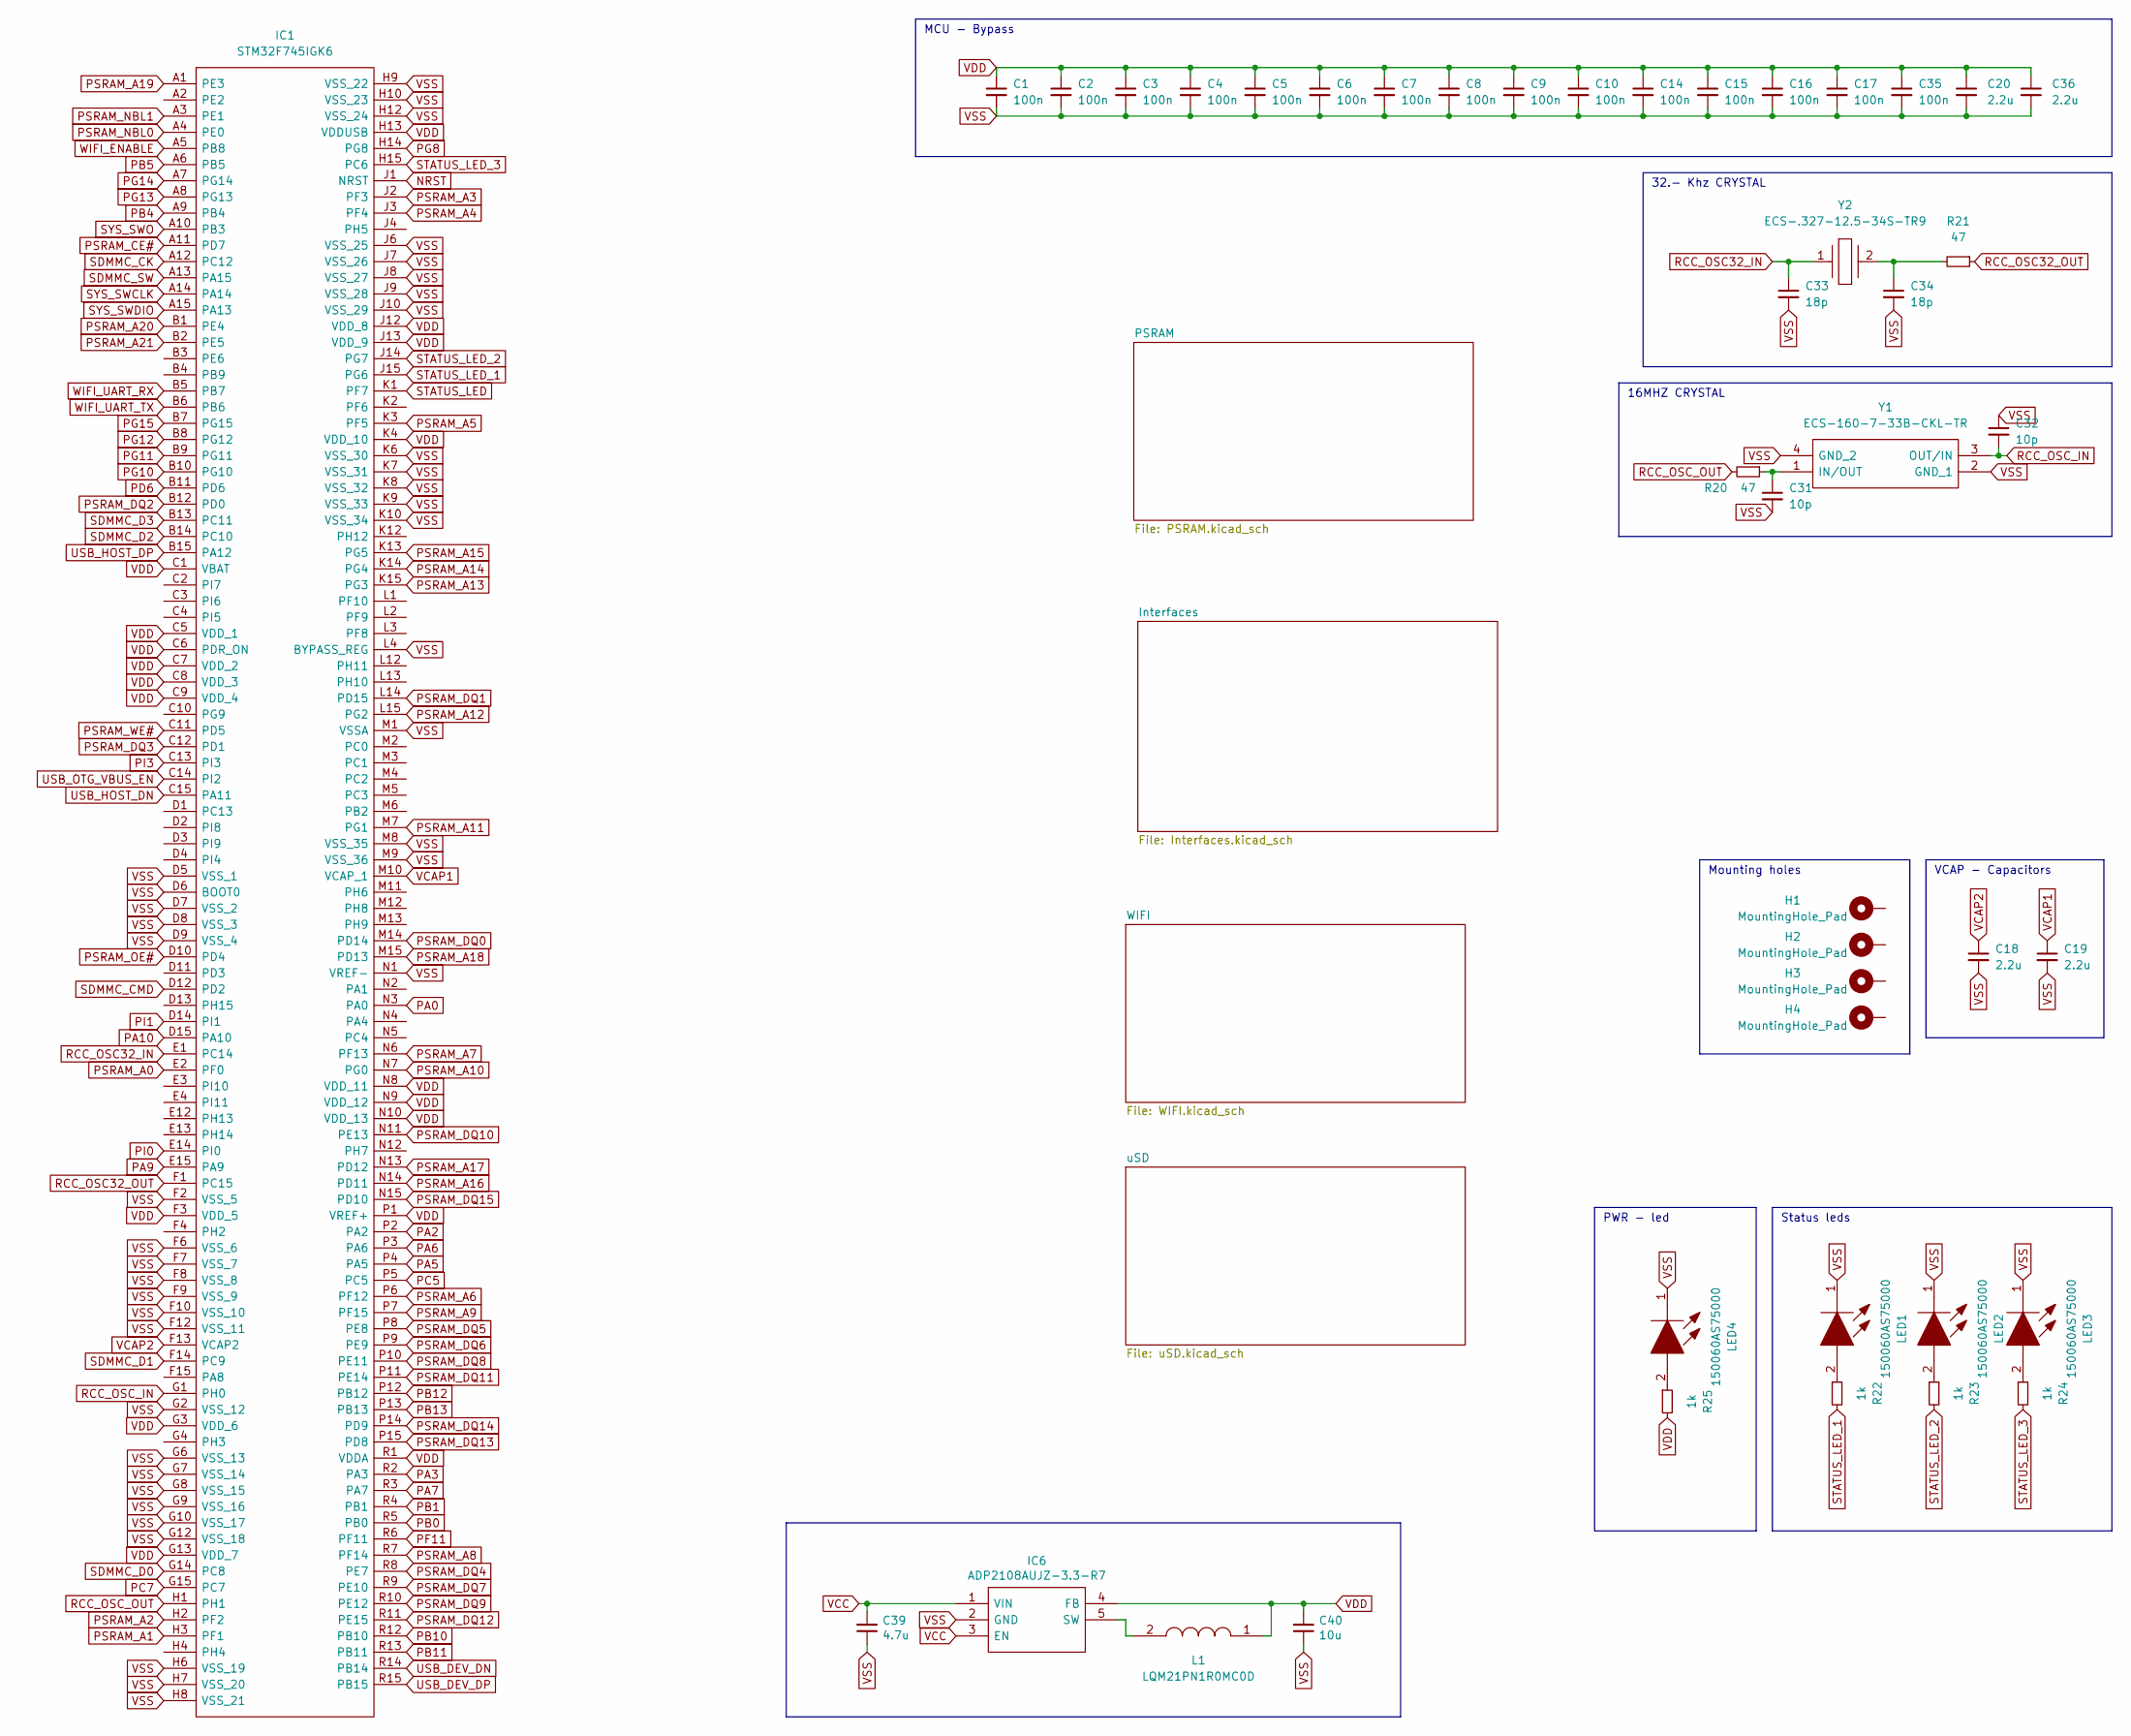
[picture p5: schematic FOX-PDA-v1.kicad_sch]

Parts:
C1, C2, C3, C4, C5, C6, C7, C8, C9, C10, C14, C15, C16, C17, C35: 100n; C_0402_1005Metric
C18, C19: 2.2u; C_0402_1005Metric
C20, C36: 2.2u; C_0603_1608Metric
C31, C32: 10p; C_0402_1005Metric
C33, C34: 18p; C_0402_1005Metric
C39: 4.7u; C_0603_1608Metric
C40: 10u; C_0603_1608Metric
H1, H2, H3, H4: MountingHole_Pad; MountingHole_3.2mm_M3_Pad_Via
IC1: STM32F745IGK6; BGA201C65P15X15_1000X1000X60; Mouser Part Number 511-STM32F745IGK6
IC6: ADP2108AUJZ-3.3-R7; SOT95P280X100-5N; Mouser Part Number 584-ADP2108AUJZ3.3R7
L1: LQM21PN1R0MC0D; Mouser Part Number 81-LQM21PN1R0MC0D
LED1, LED2, LED3, LED4: 150060AS75000; LEDC1608X80N; Mouser Part Number 710-150060AS75000
R20, R21: 47; R_0402_1005Metric
R22, R23, R24, R25: 1k; R_0402_1005Metric
Y1: ECS-160-7-33B-CKL-TR; ECS160733BCKLTR; Manufacturer_Part_Number ECS-160-7-33B-CKL-TR
Y2: ECS-.327-12.5-34S-TR9; ECS32712534STR9; Mouser Part Number 520-ECS-32712534STR9

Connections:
NRST: IC1.J1 (NRST); also elsewhere on the board
unnamed: C31.1, R20.1, Y1.1 (IN/OUT)
unnamed: C34.1, R21.2, Y2.2
unnamed: IC6.5 (SW), L1.2
unnamed: LED1.2, R22.1
unnamed: LED2.2, R23.1
unnamed: LED3.2, R24.1
unnamed: LED4.2, R25.1
PA0: IC1.N3 (PA0); also elsewhere on the board
PA2: IC1.P2 (PA2); also elsewhere on the board
PA3: IC1.R2 (PA3); also elsewhere on the board
PA5: IC1.P4 (PA5); also elsewhere on the board
PA6: IC1.P3 (PA6); also elsewhere on the board
PA7: IC1.R3 (PA7); also elsewhere on the board
PA9: IC1.E15 (PA9); also elsewhere on the board
PA10: IC1.D15 (PA10); also elsewhere on the board
PB0: IC1.R5 (PB0); also elsewhere on the board
PB1: IC1.R4 (PB1); also elsewhere on the board
PB4: IC1.A9 (PB4); also elsewhere on the board
PB5: IC1.A6 (PB5); also elsewhere on the board
PB10: IC1.R12 (PB10); also elsewhere on the board
PB11: IC1.R13 (PB11); also elsewhere on the board
PB12: IC1.P12 (PB12); also elsewhere on the board
PB13: IC1.P13 (PB13); also elsewhere on the board
PC5: IC1.P5 (PC5); also elsewhere on the board
PC7: IC1.G15 (PC7); also elsewhere on the board
PD6: IC1.B11 (PD6); also elsewhere on the board
PF11: IC1.R6 (PF11); also elsewhere on the board
PG8: IC1.H14 (PG8); also elsewhere on the board
PG10: IC1.B10 (PG10); also elsewhere on the board
PG11: IC1.B9 (PG11); also elsewhere on the board
PG12: IC1.B8 (PG12); also elsewhere on the board
PG13: IC1.A8 (PG13); also elsewhere on the board
PG14: IC1.A7 (PG14); also elsewhere on the board
PG15: IC1.B7 (PG15); also elsewhere on the board
PI0: IC1.E14 (PI0); also elsewhere on the board
PI1: IC1.D14 (PI1); also elsewhere on the board
PI3: IC1.C13 (PI3); also elsewhere on the board
PSRAM_A0: IC1.E2 (PF0); also elsewhere on the board
PSRAM_A1: IC1.H3 (PF1); also elsewhere on the board
PSRAM_A2: IC1.H2 (PF2); also elsewhere on the board
PSRAM_A3: IC1.J2 (PF3); also elsewhere on the board
PSRAM_A4: IC1.J3 (PF4); also elsewhere on the board
PSRAM_A5: IC1.K3 (PF5); also elsewhere on the board
PSRAM_A6: IC1.P6 (PF12); also elsewhere on the board
PSRAM_A7: IC1.N6 (PF13); also elsewhere on the board
PSRAM_A8: IC1.R7 (PF14); also elsewhere on the board
PSRAM_A9: IC1.P7 (PF15); also elsewhere on the board
PSRAM_A10: IC1.N7 (PG0); also elsewhere on the board
PSRAM_A11: IC1.M7 (PG1); also elsewhere on the board
PSRAM_A12: IC1.L15 (PG2); also elsewhere on the board
PSRAM_A13: IC1.K15 (PG3); also elsewhere on the board
PSRAM_A14: IC1.K14 (PG4); also elsewhere on the board
PSRAM_A15: IC1.K13 (PG5); also elsewhere on the board
PSRAM_A16: IC1.N14 (PD11); also elsewhere on the board
PSRAM_A17: IC1.N13 (PD12); also elsewhere on the board
PSRAM_A18: IC1.M15 (PD13); also elsewhere on the board
PSRAM_A19: IC1.A1 (PE3); also elsewhere on the board
PSRAM_A20: IC1.B1 (PE4); also elsewhere on the board
PSRAM_A21: IC1.B2 (PE5); also elsewhere on the board
PSRAM_CE#: IC1.A11 (PD7); also elsewhere on the board
PSRAM_DQ0: IC1.M14 (PD14); also elsewhere on the board
PSRAM_DQ1: IC1.L14 (PD15); also elsewhere on the board
PSRAM_DQ2: IC1.B12 (PD0); also elsewhere on the board
PSRAM_DQ3: IC1.C12 (PD1); also elsewhere on the board
PSRAM_DQ4: IC1.R8 (PE7); also elsewhere on the board
PSRAM_DQ5: IC1.P8 (PE8); also elsewhere on the board
PSRAM_DQ6: IC1.P9 (PE9); also elsewhere on the board
PSRAM_DQ7: IC1.R9 (PE10); also elsewhere on the board
PSRAM_DQ8: IC1.P10 (PE11); also elsewhere on the board
PSRAM_DQ9: IC1.R10 (PE12); also elsewhere on the board
PSRAM_DQ10: IC1.N11 (PE13); also elsewhere on the board
PSRAM_DQ11: IC1.P11 (PE14); also elsewhere on the board
PSRAM_DQ12: IC1.R11 (PE15); also elsewhere on the board
PSRAM_DQ13: IC1.P15 (PD8); also elsewhere on the board
PSRAM_DQ14: IC1.P14 (PD9); also elsewhere on the board
PSRAM_DQ15: IC1.N15 (PD10); also elsewhere on the board
PSRAM_NBL0: IC1.A4 (PE0); also elsewhere on the board
PSRAM_NBL1: IC1.A3 (PE1); also elsewhere on the board
PSRAM_OE#: IC1.D10 (PD4); also elsewhere on the board
PSRAM_WE#: IC1.C11 (PD5); also elsewhere on the board
RCC_OSC32_IN: C33.1, IC1.E1 (PC14), Y2.1
RCC_OSC32_OUT: IC1.F1 (PC15), R21.1
RCC_OSC_IN: C32.2, IC1.G1 (PH0), Y1.3 (OUT/IN)
RCC_OSC_OUT: IC1.H1, R20.2
SDMMC_CK: IC1.A12 (PC12); also elsewhere on the board
SDMMC_CMD: IC1.D12 (PD2); also elsewhere on the board
SDMMC_D0: IC1.G14 (PC8); also elsewhere on the board
SDMMC_D1: IC1.F14 (PC9); also elsewhere on the board
SDMMC_D2: IC1.B14 (PC10); also elsewhere on the board
SDMMC_D3: IC1.B13 (PC11); also elsewhere on the board
SDMMC_SW: IC1.A13 (PA15); also elsewhere on the board
STATUS_LED: IC1.K1 (PF7)
STATUS_LED_1: IC1.J15 (PG6), R22.2
STATUS_LED_2: IC1.J14 (PG7), R23.2
STATUS_LED_3: IC1.H15 (PC6), R24.2
SYS_SWCLK: IC1.A14; also elsewhere on the board
SYS_SWDIO: IC1.A15 (PA13); also elsewhere on the board
SYS_SWO: IC1.A10 (PB3); also elsewhere on the board
USB_DEV_DN: IC1.R14 (PB14); also elsewhere on the board
USB_DEV_DP: IC1.R15 (PB15); also elsewhere on the board
USB_HOST_DN: IC1.C15 (PA11); also elsewhere on the board
USB_HOST_DP: IC1.B15 (PA12); also elsewhere on the board
USB_OTG_VBUS_EN: IC1.C14 (PI2)
VCAP1: C19.1, IC1.M10 (VCAP_1)
VCAP2: C18.1, IC1.F13 (VCAP2)
VCC: C39.2, IC6.1 (VIN), IC6.3 (EN); also elsewhere on the board
VDD: C1.1, C2.1, C3.1, C4.1, C5.1, C6.1, C7.1, C8.1, C9.1, C10.1, C14.1, C15.1, C16.1, C17.1, C20.1, C35.1, C36.1, C40.2, IC1.C1 (VBAT), IC1.C5 (VDD_1), IC1.C6 (PDR_ON), IC1.C7 (VDD_2), IC1.C8 (VDD_3), IC1.C9 (VDD_4), IC1.F3 (VDD_5), IC1.G3 (VDD_6), IC1.G13 (VDD_7), IC1.H13 (VDDUSB), IC1.J12 (VDD_8), IC1.J13 (VDD_9), IC1.K4 (VDD_10), IC1.N8 (VDD_11), IC1.N9 (VDD_12), IC1.N10 (VDD_13), IC1.P1 (VREF+), IC1.R1 (VDDA), IC6.4 (FB), L1.1, R25.2; also elsewhere on the board
VSS: C1.2, C2.2, C3.2, C4.2, C5.2, C6.2, C7.2, C8.2, C9.2, C10.2, C14.2, C15.2, C16.2, C17.2, C18.2, C19.2, C20.2, C31.2, C32.1, C33.2, C34.2, C35.2, C36.2, C39.1, C40.1, IC1.D5 (VSS_1), IC1.D6 (BOOT0), IC1.D7 (VSS_2), IC1.D8 (VSS_3), IC1.D9 (VSS_4), IC1.F2 (VSS_5), IC1.F6 (VSS_6), IC1.F7 (VSS_7), IC1.F8 (VSS_8), IC1.F9 (VSS_9), IC1.F10 (VSS_10), IC1.F12 (VSS_11), IC1.G2 (VSS_12), IC1.G6 (VSS_13), IC1.G7 (VSS_14), IC1.G8 (VSS_15), IC1.G9 (VSS_16), IC1.G10 (VSS_17), IC1.G12 (VSS_18), IC1.H6 (VSS_19), IC1.H7 (VSS_20), IC1.H8 (VSS_21), IC1.H9 (VSS_22), IC1.H10 (VSS_23), IC1.H12 (VSS_24), IC1.J6 (VSS_25), IC1.J7 (VSS_26), IC1.J8 (VSS_27), IC1.J9 (VSS_28), IC1.J10 (VSS_29), IC1.K6 (VSS_30), IC1.K7 (VSS_31), IC1.K8 (VSS_32), IC1.K9 (VSS_33), IC1.K10 (VSS_34), IC1.L4 (BYPASS_REG), IC1.M1 (VSSA), IC1.M8 (VSS_35), IC1.M9 (VSS_36), IC1.N1 (VREF-), IC6.2 (GND), LED1.1, LED2.1, LED3.1, LED4.1, Y1.2 (GND_1), Y1.4 (GND_2); also elsewhere on the board
WIFI_ENABLE: IC1.A5 (PB8); also elsewhere on the board
WIFI_UART_RX: IC1.B5 (PB7); also elsewhere on the board
WIFI_UART_TX: IC1.B6; also elsewhere on the board

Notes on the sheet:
16MHZ CRYSTAL
32.- Khz CRYSTAL
PWR - led
Status leds
VCAP - Capacitors
Mounting holes
MCU - Bypass

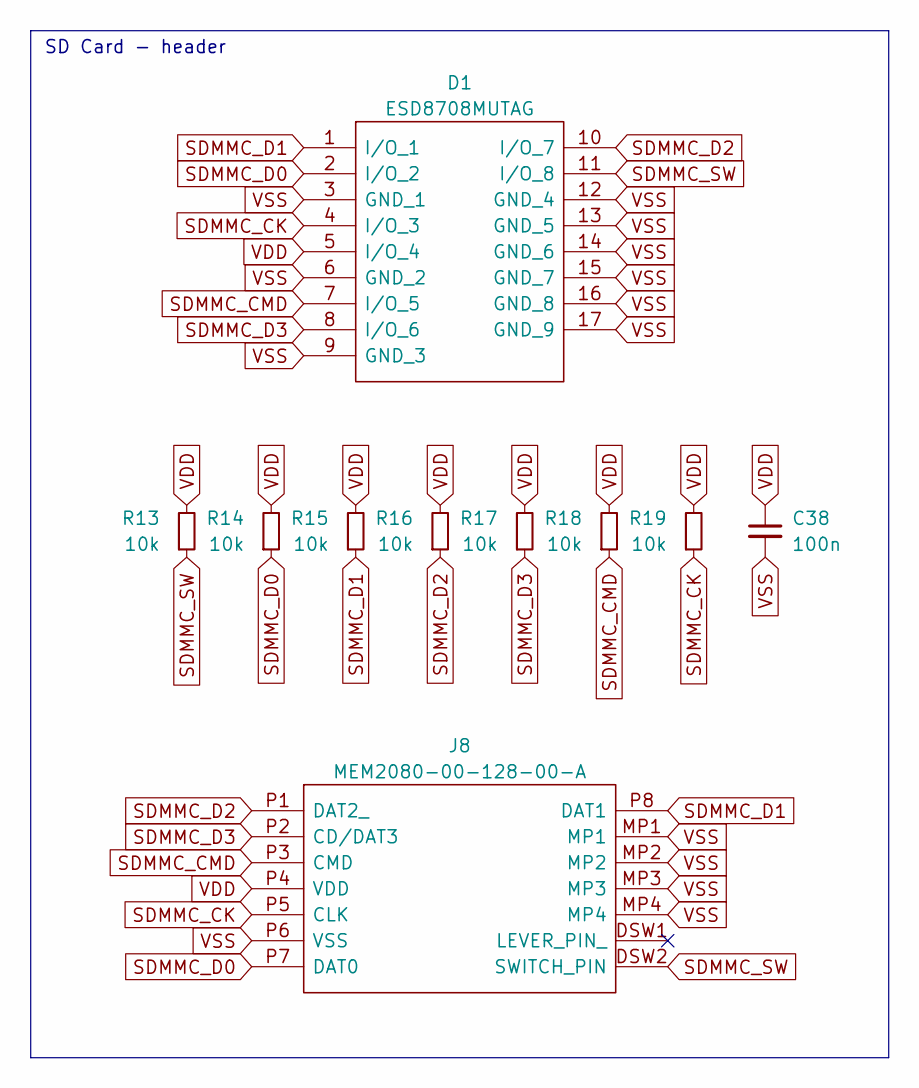
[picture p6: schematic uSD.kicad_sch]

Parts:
C38: 100n; C_0402_1005Metric
D1: ESD8708MUTAG; Mouser Part Number 863-ESD8708MUTAG
J8: MEM2080-00-128-00-A; MEM20800012800A; Mouser Part Number 640-MEM2080-0012800A
R13, R14, R15, R16, R17, R18, R19: 10k; R_0402_1005Metric

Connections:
SDMMC_CK: D1.4 (I/O_3), J8.P5 (CLK), R19.1; also elsewhere on the board
SDMMC_CMD: D1.7 (I/O_5), J8.P3 (CMD), R18.1; also elsewhere on the board
SDMMC_D0: D1.2 (I/O_2), J8.P7 (DAT0), R14.1; also elsewhere on the board
SDMMC_D1: D1.1 (I/O_1), J8.P8 (DAT1), R15.1; also elsewhere on the board
SDMMC_D2: D1.10 (I/O_7), J8.P1 (DAT2_), R16.1; also elsewhere on the board
SDMMC_D3: D1.8 (I/O_6), J8.P2 (CD/DAT3), R17.1; also elsewhere on the board
SDMMC_SW: D1.11 (I/O_8), J8.DSW2 (SWITCH_PIN), R13.1; also elsewhere on the board
VDD: C38.1, D1.5 (I/O_4), J8.P4 (VDD), R13.2, R14.2, R15.2, R16.2, R17.2, R18.2, R19.2; also elsewhere on the board
VSS: C38.2, D1.3 (GND_1), D1.6 (GND_2), D1.9 (GND_3), D1.12 (GND_4), D1.13 (GND_5), D1.14 (GND_6), D1.15 (GND_7), D1.16 (GND_8), D1.17 (GND_9), J8.MP1, J8.MP2, J8.MP3, J8.MP4, J8.P6 (VSS); also elsewhere on the board

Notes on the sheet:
SD Card - header

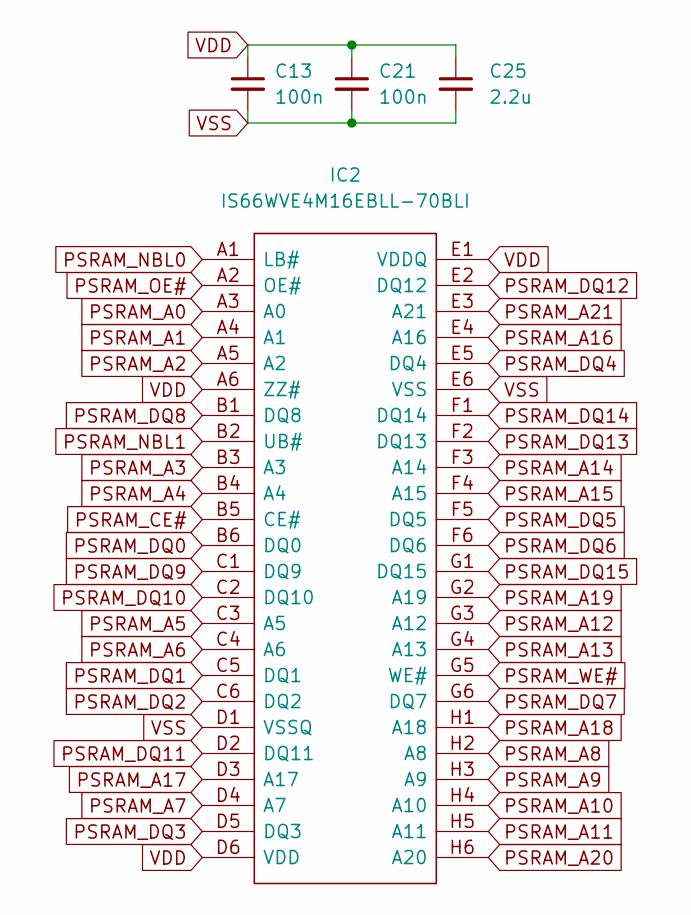
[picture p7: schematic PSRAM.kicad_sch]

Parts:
C13, C21: 100n; C_0402_1005Metric
C25: 2.2u; C_0603_1608Metric
IC2: IS66WVE4M16EBLL-70BLI; BGA48C75P6X8_600X800X120; Mouser Part Number 870-66E4M16EBLL70BLI

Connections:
PSRAM_A0: IC2.A3 (A0); also elsewhere on the board
PSRAM_A1: IC2.A4 (A1); also elsewhere on the board
PSRAM_A2: IC2.A5 (A2); also elsewhere on the board
PSRAM_A3: IC2.B3 (A3); also elsewhere on the board
PSRAM_A4: IC2.B4 (A4); also elsewhere on the board
PSRAM_A5: IC2.C3 (A5); also elsewhere on the board
PSRAM_A6: IC2.C4 (A6); also elsewhere on the board
PSRAM_A7: IC2.D4 (A7); also elsewhere on the board
PSRAM_A8: IC2.H2 (A8); also elsewhere on the board
PSRAM_A9: IC2.H3 (A9); also elsewhere on the board
PSRAM_A10: IC2.H4 (A10); also elsewhere on the board
PSRAM_A11: IC2.H5 (A11); also elsewhere on the board
PSRAM_A12: IC2.G3 (A12); also elsewhere on the board
PSRAM_A13: IC2.G4 (A13); also elsewhere on the board
PSRAM_A14: IC2.F3 (A14); also elsewhere on the board
PSRAM_A15: IC2.F4 (A15); also elsewhere on the board
PSRAM_A16: IC2.E4 (A16); also elsewhere on the board
PSRAM_A17: IC2.D3 (A17); also elsewhere on the board
PSRAM_A18: IC2.H1 (A18); also elsewhere on the board
PSRAM_A19: IC2.G2 (A19); also elsewhere on the board
PSRAM_A20: IC2.H6 (A20); also elsewhere on the board
PSRAM_A21: IC2.E3 (A21); also elsewhere on the board
PSRAM_CE#: IC2.B5 (CE#); also elsewhere on the board
PSRAM_DQ0: IC2.B6 (DQ0); also elsewhere on the board
PSRAM_DQ1: IC2.C5 (DQ1); also elsewhere on the board
PSRAM_DQ2: IC2.C6 (DQ2); also elsewhere on the board
PSRAM_DQ3: IC2.D5 (DQ3); also elsewhere on the board
PSRAM_DQ4: IC2.E5 (DQ4); also elsewhere on the board
PSRAM_DQ5: IC2.F5 (DQ5); also elsewhere on the board
PSRAM_DQ6: IC2.F6 (DQ6); also elsewhere on the board
PSRAM_DQ7: IC2.G6 (DQ7); also elsewhere on the board
PSRAM_DQ8: IC2.B1 (DQ8); also elsewhere on the board
PSRAM_DQ9: IC2.C1 (DQ9); also elsewhere on the board
PSRAM_DQ10: IC2.C2 (DQ10); also elsewhere on the board
PSRAM_DQ11: IC2.D2 (DQ11); also elsewhere on the board
PSRAM_DQ12: IC2.E2 (DQ12); also elsewhere on the board
PSRAM_DQ13: IC2.F2 (DQ13); also elsewhere on the board
PSRAM_DQ14: IC2.F1 (DQ14); also elsewhere on the board
PSRAM_DQ15: IC2.G1 (DQ15); also elsewhere on the board
PSRAM_NBL0: IC2.A1 (LB#); also elsewhere on the board
PSRAM_NBL1: IC2.B2 (UB#); also elsewhere on the board
PSRAM_OE#: IC2.A2 (OE#); also elsewhere on the board
PSRAM_WE#: IC2.G5 (WE#); also elsewhere on the board
VDD: C13.1, C21.1, C25.1, IC2.A6 (ZZ#), IC2.D6 (VDD), IC2.E1 (VDDQ); also elsewhere on the board
VSS: C13.2, C21.2, C25.2, IC2.D1 (VSSQ), IC2.E6 (VSS); also elsewhere on the board

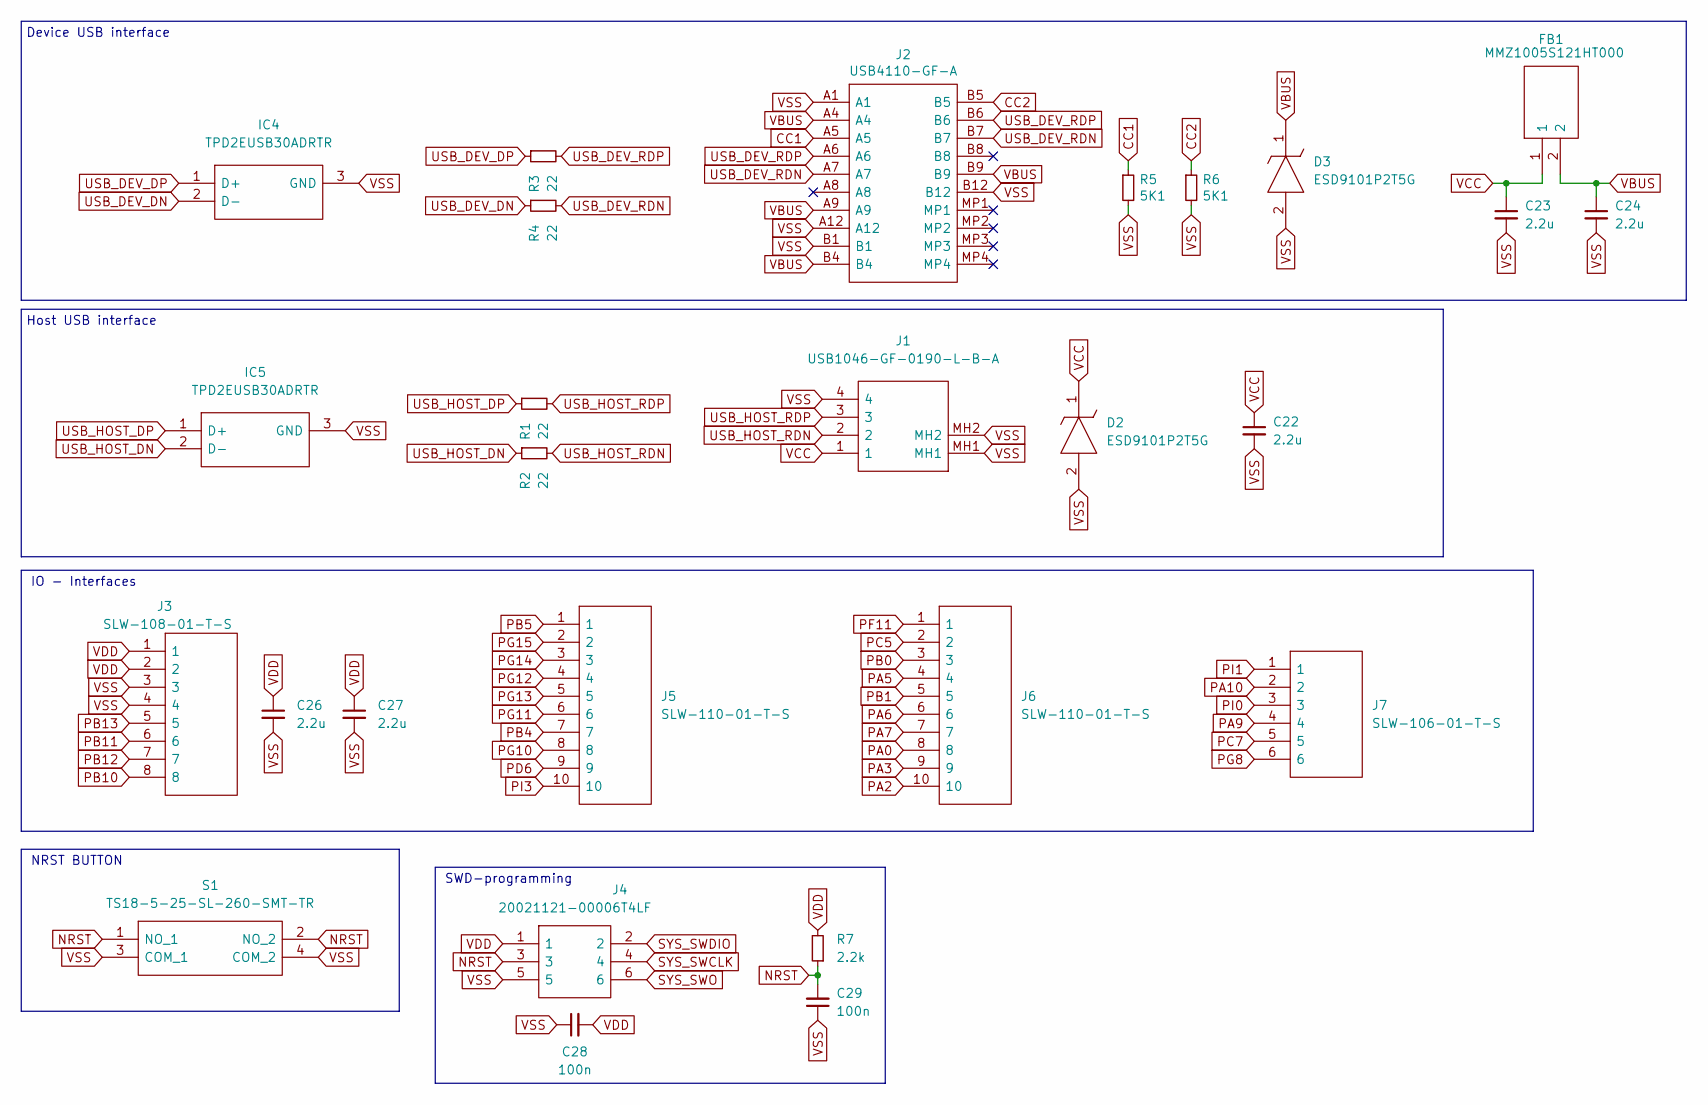
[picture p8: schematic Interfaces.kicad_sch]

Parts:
C22, C23, C24, C26, C27: 2.2u; C_0603_1608Metric
C28, C29: 100n; C_0402_1005Metric
D2, D3: ESD9101P2T5G; SODFL1006X40N; Mouser Part Number 863-ESD9101P2T5G
FB1: MMZ1005S121HT000; BEADC1005X55N; Mouser Part Number 810-MMZ1005S121HT000
IC4, IC5: TPD2EUSB30ADRTR; SOT35P100X50-3N; Mouser Part Number 595-TPD2EUSB30ADRTR
J1: USB1046-GF-0190-L-B-A; USB1046GF0190LBA; Mouser Part Number 640-USB1046GF0190LBA
J2: USB4110-GF-A; USB4110GFA; Mouser Part Number 640-USB4110-GF-A
J3: SLW-108-01-T-S; SLW-108-01-X-S; Mouser Part Number 200-SLW10801TS
J4: 20021121-00006T4LF; HUSSP6W41P127_2X3_381X343X440P; Mouser Part Number 649-221121-00006T4LF
J5, J6: SLW-110-01-T-S; SLW-110-01-X-S; Mouser Part Number 200-SLW11001TS
J7: SLW-106-01-T-S; SLW-106-01-X-S; Mouser Part Number 200-SLW10601TS
R1, R2, R3, R4: 22; R_0402_1005Metric
R5, R6: 5K1; R_0402_1005Metric
R7: 2.2k; R_0402_1005Metric
S1: TS18-5-25-SL-260-SMT-TR; TS18525SL260SMTTR; Mouser Part Number 179-TS18525SL260SMTT

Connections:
CC1: J2.A5, R5.1
CC2: J2.B5, R6.1
NRST: C29.2, J4.3, R7.1, S1.1 (NO_1), S1.2 (NO_2); also elsewhere on the board
PA0: J6.8; also elsewhere on the board
PA2: J6.10; also elsewhere on the board
PA3: J6.9; also elsewhere on the board
PA5: J6.4; also elsewhere on the board
PA6: J6.6; also elsewhere on the board
PA7: J6.7; also elsewhere on the board
PA9: J7.4; also elsewhere on the board
PA10: J7.2; also elsewhere on the board
PB0: J6.3; also elsewhere on the board
PB1: J6.5; also elsewhere on the board
PB4: J5.7; also elsewhere on the board
PB5: J5.1; also elsewhere on the board
PB10: J3.8; also elsewhere on the board
PB11: J3.6; also elsewhere on the board
PB12: J3.7; also elsewhere on the board
PB13: J3.5; also elsewhere on the board
PC5: J6.2; also elsewhere on the board
PC7: J7.5; also elsewhere on the board
PD6: J5.9; also elsewhere on the board
PF11: J6.1; also elsewhere on the board
PG8: J7.6; also elsewhere on the board
PG10: J5.8; also elsewhere on the board
PG11: J5.6; also elsewhere on the board
PG12: J5.4; also elsewhere on the board
PG13: J5.5; also elsewhere on the board
PG14: J5.3; also elsewhere on the board
PG15: J5.2; also elsewhere on the board
PI0: J7.3; also elsewhere on the board
PI1: J7.1; also elsewhere on the board
PI3: J5.10; also elsewhere on the board
SYS_SWCLK: J4.4; also elsewhere on the board
SYS_SWDIO: J4.2; also elsewhere on the board
SYS_SWO: J4.6; also elsewhere on the board
USB_DEV_DN: IC4.2 (D-), R4.1; also elsewhere on the board
USB_DEV_DP: IC4.1 (D+), R3.1; also elsewhere on the board
USB_DEV_RDN: J2.A7, J2.B7, R4.2
USB_DEV_RDP: J2.A6, J2.B6, R3.2
USB_HOST_DN: IC5.2 (D-), R2.1; also elsewhere on the board
USB_HOST_DP: IC5.1 (D+), R1.1; also elsewhere on the board
USB_HOST_RDN: J1.2, R2.2
USB_HOST_RDP: J1.3, R1.2
VBUS: C24.1, D3.1, FB1.2, J2.A4, J2.A9, J2.B4, J2.B9
VCC: C22.1, C23.1, D2.1, FB1.1, J1.1; also elsewhere on the board
VDD: C26.1, C27.1, C28.2, J3.1, J3.2, J4.1, R7.2; also elsewhere on the board
VSS: C22.2, C23.2, C24.2, C26.2, C27.2, C28.1, C29.1, D2.2, D3.2, IC4.3 (GND), IC5.3 (GND), J1.4, J1.MH1, J1.MH2, J2.A1, J2.A12, J2.B1, J2.B12, J3.3, J3.4, J4.5, R5.2, R6.2, S1.3 (COM_1), S1.4 (COM_2); also elsewhere on the board

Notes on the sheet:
NRST BUTTON
Device USB interface
SWD-programming
Host USB interface
IO - Interfaces

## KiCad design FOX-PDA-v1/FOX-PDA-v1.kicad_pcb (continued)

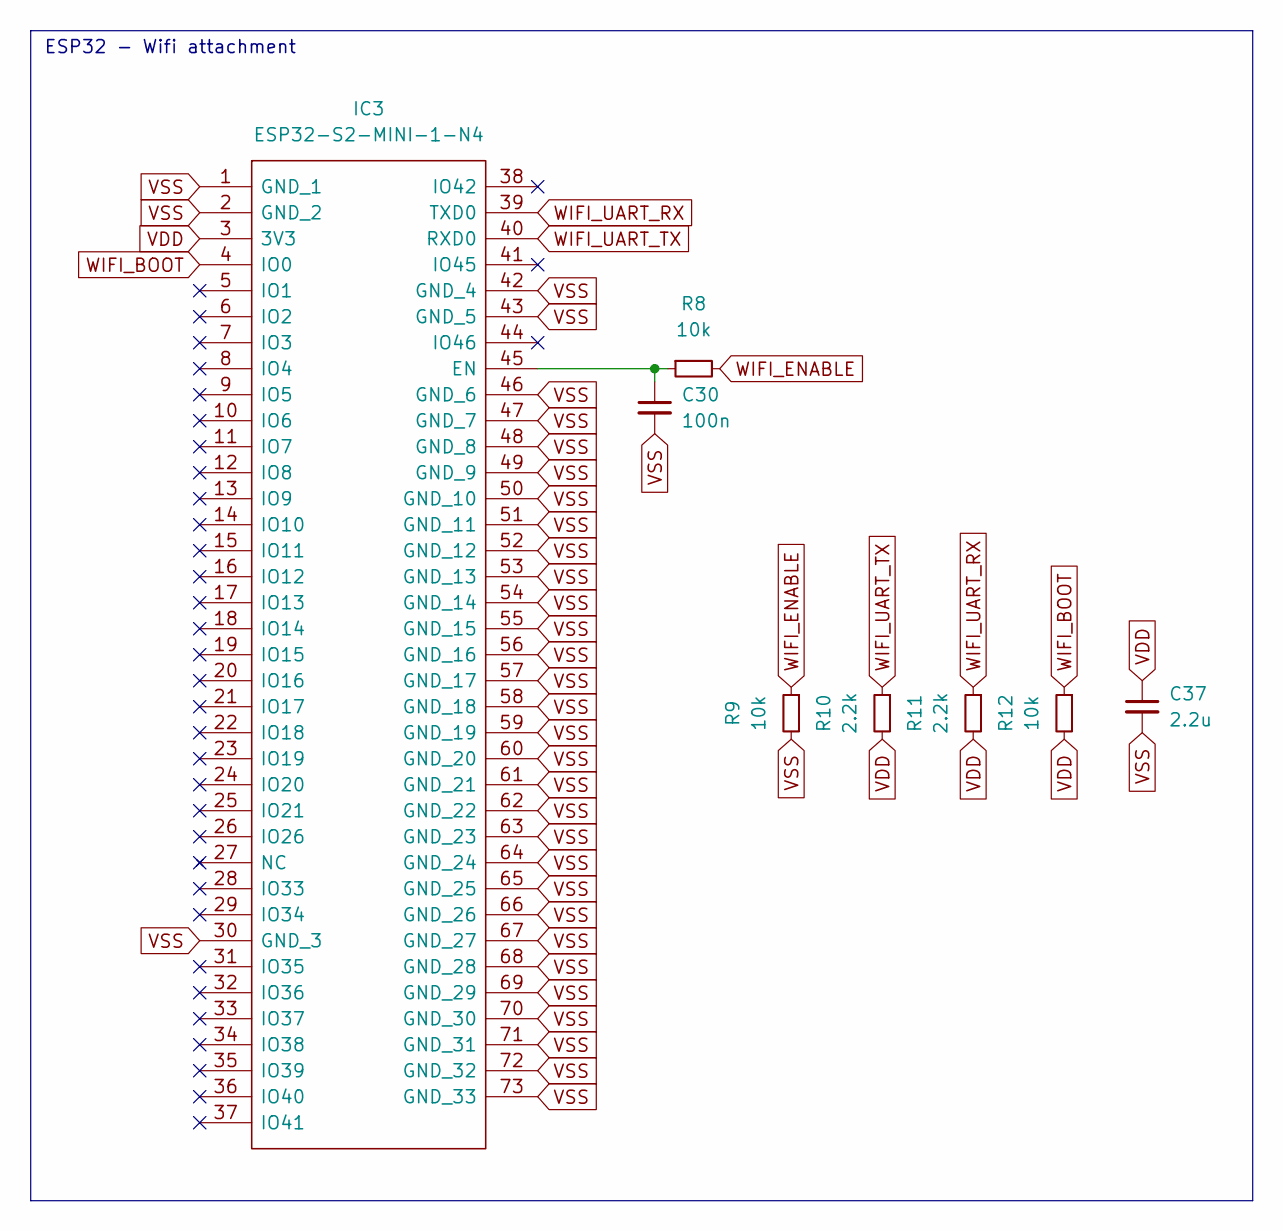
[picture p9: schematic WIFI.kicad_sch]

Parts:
C30: 100n; C_0402_1005Metric
C37: 2.2u; C_0603_1608Metric
IC3: ESP32-S2-MINI-1-N4; ESP32S2MINI1N4; Mouser Part Number 356-ESP32-S2-MINI-1
R8, R9, R12: 10k; R_0402_1005Metric
R10, R11: 2.2k; R_0402_1005Metric

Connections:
unnamed: C30.1, IC3.45 (EN), R8.1
VDD: C37.1, IC3.3 (3V3), R10.2, R11.2, R12.2; also elsewhere on the board
VSS: C30.2, C37.2, IC3.1 (GND_1), IC3.2 (GND_2), IC3.30 (GND_3), IC3.42 (GND_4), IC3.43 (GND_5), IC3.46 (GND_6), IC3.47 (GND_7), IC3.48 (GND_8), IC3.49 (GND_9), IC3.50 (GND_10), IC3.51 (GND_11), IC3.52 (GND_12), IC3.53 (GND_13), IC3.54 (GND_14), IC3.55 (GND_15), IC3.56 (GND_16), IC3.57 (GND_17), IC3.58 (GND_18), IC3.59 (GND_19), IC3.60 (GND_20), IC3.61 (GND_21), IC3.62 (GND_22), IC3.63 (GND_23), IC3.64 (GND_24), IC3.65 (GND_25), IC3.66 (GND_26), IC3.67 (GND_27), IC3.68 (GND_28), IC3.69 (GND_29), IC3.70 (GND_30), IC3.71 (GND_31), IC3.72 (GND_32), IC3.73 (GND_33), R9.2; also elsewhere on the board
WIFI_BOOT: IC3.4 (IO0), R12.1
WIFI_ENABLE: R8.2, R9.1; also elsewhere on the board
WIFI_UART_RX: IC3.39 (TXD0), R11.1; also elsewhere on the board
WIFI_UART_TX: IC3.40 (RXD0), R10.1; also elsewhere on the board

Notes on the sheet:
ESP32 - Wifi attachment

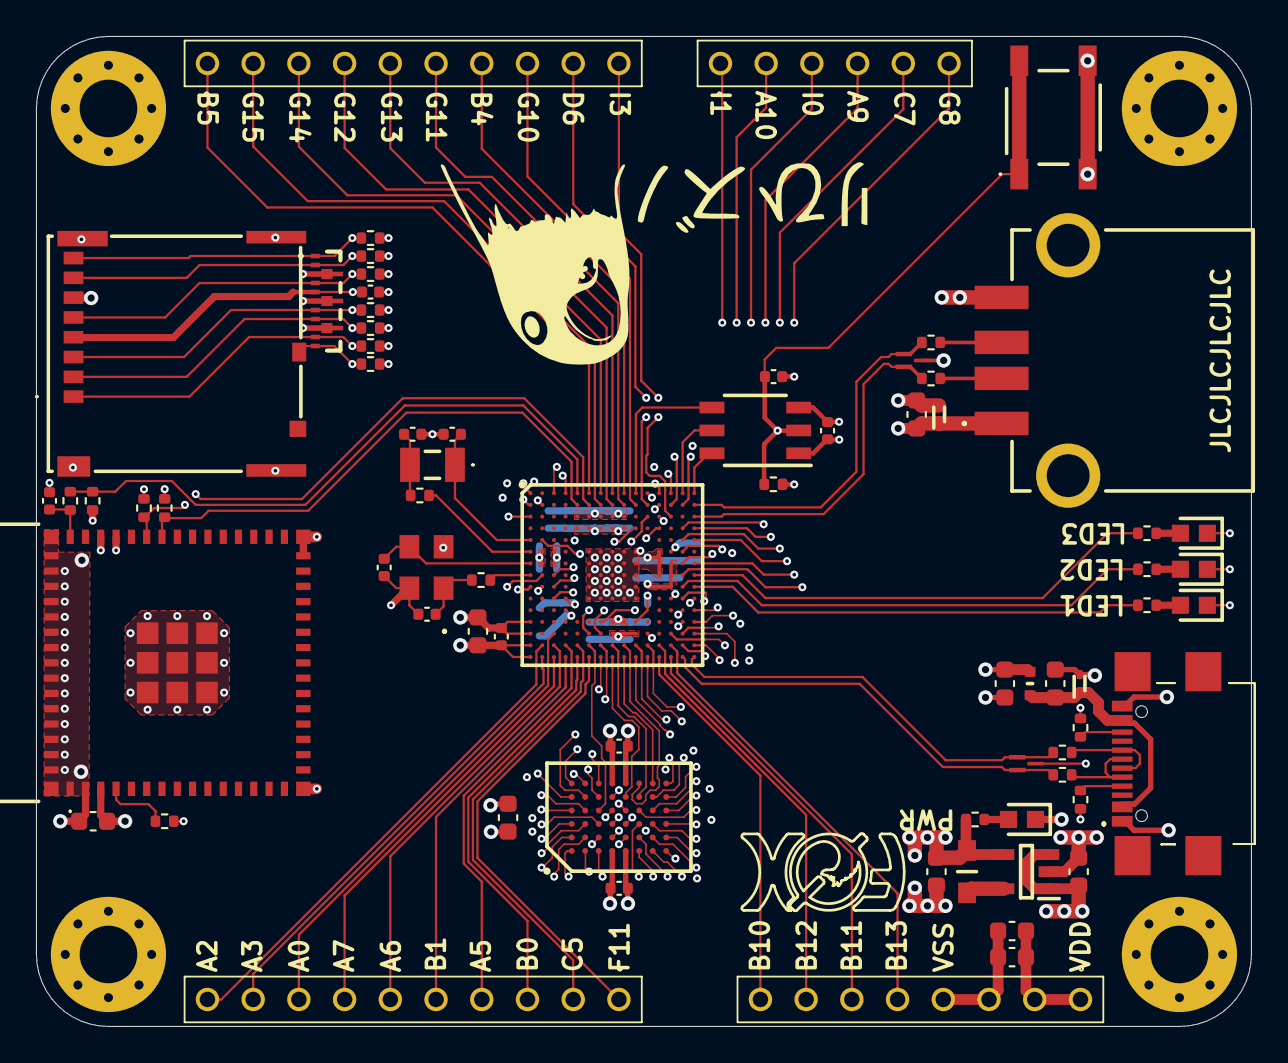
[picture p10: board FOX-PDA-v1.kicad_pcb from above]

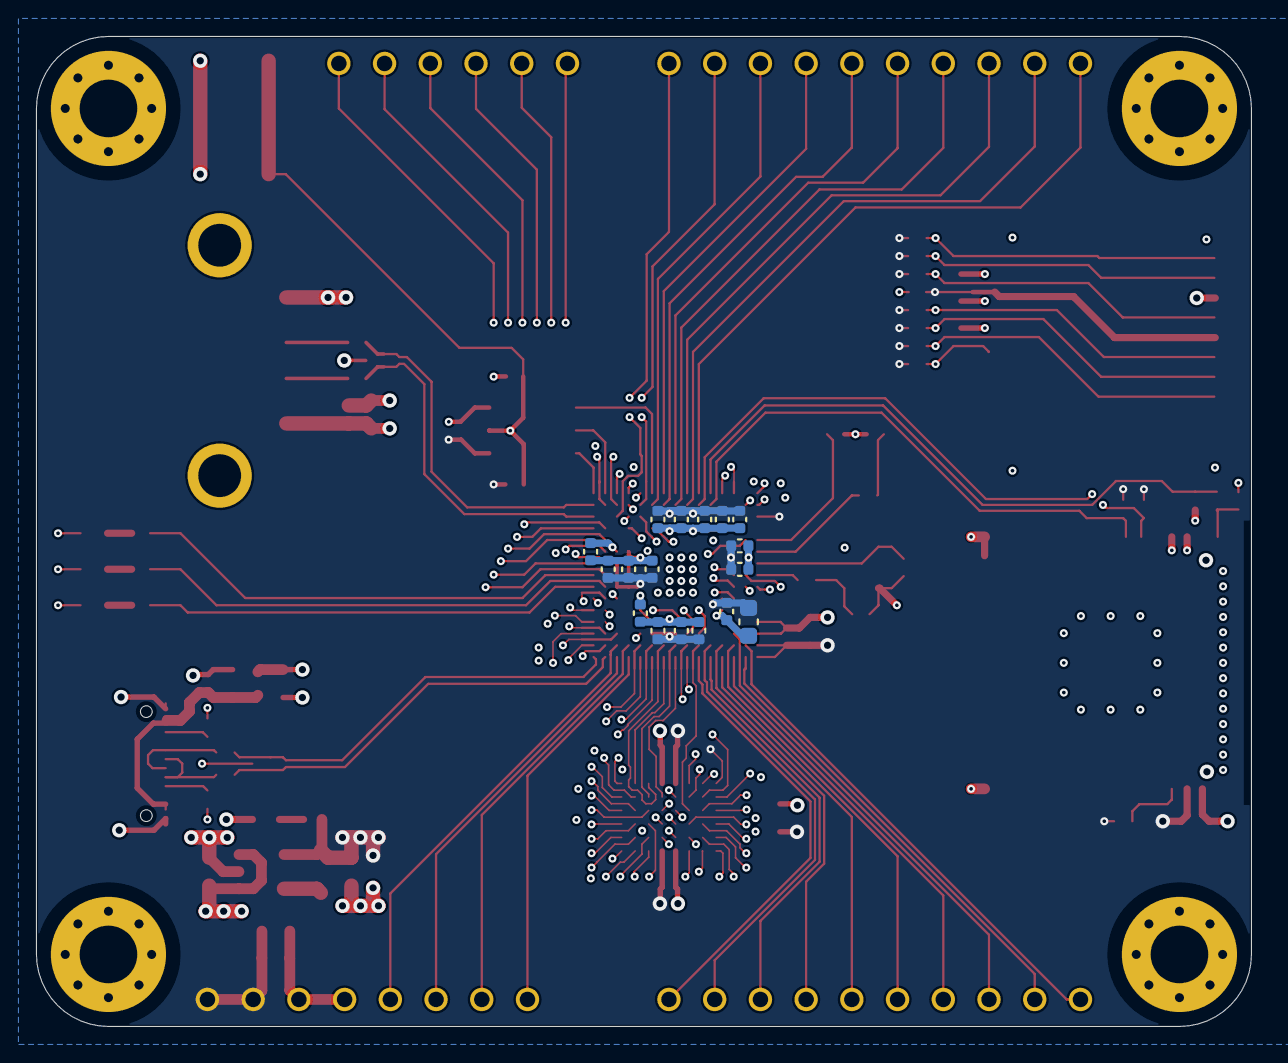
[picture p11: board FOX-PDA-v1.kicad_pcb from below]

Board: 6 copper layers, 67.5 x 55.0 mm, 93 parts (17 on the bottom side), 119 nets.

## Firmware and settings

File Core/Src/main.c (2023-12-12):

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
/* Includes ------------------------------------------------------------------*/
#include "main.h"
#include "fatfs.h"
#include "usb_device.h"
#include "usb_host.h"

/* USER CODE BEGIN Includes */
#include "usbd_cdc_if.h"
#include "string.h"
#include "stm32f7xx_ll_fmc.h"
#include "math.h"

#include "Ffunctions/f_debug.h"
#include "System/System.h"

#include "AoC/AdventOfCode.h"
#include "AoC/AdventOfCode_Includes.h"
/* USER CODE END Includes */

/* USER CODE BEGIN PD */
#define USB_COMMAND_CHECK		"check"		 // check
#define USB_COMMAND_TEST		"test"		 // test
#define USB_COMMAND_RELEASE		"release"	 // release
#define USB_COMMAND_LIST		"list"		 // list
#define USB_COMMAND_UPLOAD		"upload"	 // upload
#define USB_COMMAND_DELETE		"delete"	 // delete
#define USB_COMMAND_HELP		"help"		 // help
/* USER CODE END PD */

ADC_HandleTypeDef hadc1;
DMA_HandleTypeDef hdma_adc1;

SD_HandleTypeDef hsd1;
DMA_HandleTypeDef hdma_sdmmc1_rx;
DMA_HandleTypeDef hdma_sdmmc1_tx;

TIM_HandleTypeDef htim1;
TIM_HandleTypeDef htim11;

UART_HandleTypeDef huart1;

SRAM_HandleTypeDef hsram1;

/* USER CODE BEGIN PV */

// system state management
System_t system_state;

uint8_t usb_rx_buffer[1024];
uint16_t usb_rx_length;
volatile uint8_t usb_rx_ready;
volatile uint8_t usb_connected;

AdventOfCode_t aoc;

/* USER CODE END PV */

void SystemClock_Config(void);
static void MX_GPIO_Init(void);
static void MX_DMA_Init(void);
static void MX_SDMMC1_SD_Init(void);
static void MX_USART1_UART_Init(void);
static void MX_TIM1_Init(void);
static void MX_TIM11_Init(void);
static void MX_ADC1_Init(void);
static void MX_FMC_Init(void);
void MX_USB_HOST_Process(void);

/* USER CODE BEGIN 0 */

static void checkImplementation(char token_buffer[6][32])
{
	// no value given
	if(token_buffer[1][0] == 0x00)
	{
		AdventOfCode_print(AOC_CONFIG_DEBUG_VERBOSE, "No day number given!\n", strlen("No day number given!\n"));
		return;
	}

	// check value
	int32_t day = atoi(token_buffer[1]);
	if(day > 25 || day <= 0)
	{
		AdventOfCode_print(AOC_CONFIG_DEBUG_VERBOSE, "Invalid day number given!\n", strlen("Invalid day number given!\n"));
		return;
	}

	// check implementation
	char buffer[1024];
	sprintf(buffer, "Checking day %ld\n", day);
	AdventOfCode_print(AOC_CONFIG_DEBUG_VERBOSE, buffer, strlen(buffer));

	// check day
	AdventOfCode_return_t ret = aoc.aoc_func_list[day - 1](AOC_CONFIG_TEST);
	if(ret == AOC_RETURN_OK)
		AdventOfCode_print(AOC_CONFIG_DEBUG_VERBOSE, "\tState: Implemented\n", strlen("\tState: Implemented\n"));
	else AdventOfCode_print(AOC_CONFIG_DEBUG_VERBOSE, "\tState: Not implemented\n", strlen("\tState: Not implemented\n"));

	// check debug file
	FILINFO fno;
	sprintf(buffer, "day%ldt.txt", day);
	if(f_stat(buffer, &fno) == FR_OK)
		AdventOfCode_print(AOC_CONFIG_DEBUG_VERBOSE, "\tDebug: Present\n", strlen("\tDebug: Present\n"));
	else AdventOfCode_print(AOC_CONFIG_DEBUG_VERBOSE, "\tDebug: Absent\n", strlen("\tDebug: Absent\n"));

	// check release file
	sprintf(buffer, "day%ld.txt", day);
	if(f_stat(buffer, &fno) == FR_OK)
		AdventOfCode_print(AOC_CONFIG_DEBUG_VERBOSE, "\tRelease: Present\n", strlen("\tRelease: Present\n"));
	else AdventOfCode_print(AOC_CONFIG_DEBUG_VERBOSE, "\tRelease: Absent\n", strlen("\tRelease: Absent\n"));
}

static void runDebugImplementation(char token_buffer[6][32])
{
	// no value given
	if(token_buffer[1][0] == 0x00)
	{
		AdventOfCode_print(AOC_CONFIG_DEBUG_VERBOSE, "No day number given!\n", strlen("No day number given!\n"));
		return;
	}

	// check value
	int32_t day = atoi(token_buffer[1]);
	if(day > 25 || day <= 0)
	{
		AdventOfCode_print(AOC_CONFIG_DEBUG_VERBOSE, "Invalid day number given!\n", strlen("Invalid day number given!\n"));
		return;
	}

	// check implementation
	char buffer[1024];
	sprintf(buffer, "Executing debug day %ld\n", day);
	AdventOfCode_print(AOC_CONFIG_DEBUG_VERBOSE, buffer, strlen(buffer));

	// check implementationday
	AdventOfCode_return_t ret = aoc.aoc_func_list[day - 1](AOC_CONFIG_TEST);
	if(ret != AOC_RETURN_OK)
	{
		AdventOfCode_print(AOC_CONFIG_DEBUG_VERBOSE, "\tState: Not implemented\n", strlen("\tState: Not implemented\n"));
		return;
	}

	// check debug file
	FILINFO fno;
	sprintf(buffer, "day%ldt.txt", day);
	if(f_stat(buffer, &fno) != FR_OK)
	{
		AdventOfCode_print(AOC_CONFIG_DEBUG_VERBOSE, "\tDebug: Absent\n", strlen("\tDebug: Absent\n"));
		return;
	}

	// split line
	AdventOfCode_print(AOC_CONFIG_DEBUG_VERBOSE, "Start:\n", strlen("Start:\n"));

	// execute debug mode day
	uint32_t start = HAL_GetTick();
	AdventOfCode_return_t dret = aoc.aoc_func_list[day - 1](AOC_CONFIG_DEBUG_VERBOSE);
	uint32_t end = HAL_GetTick();

	// clear allocated memory
	sram_clrmem();

	// print execution results
	if(dret == AOC_RETURN_OK)
	{
		sprintf(buffer, "Succesfull: %ld ms\n", end - start);
		AdventOfCode_print(AOC_CONFIG_DEBUG_VERBOSE, buffer, strlen(buffer));
	}
	else
	{
		sprintf(buffer, "Failed: %ld ms\n", end - start);
		AdventOfCode_print(AOC_CONFIG_DEBUG_VERBOSE, buffer, strlen(buffer));
	}
}

static void runReleaseImplementation(char token_buffer[6][32])
{
	// no value given
	if(token_buffer[1][0] == 0x00)
	{
		AdventOfCode_print(AOC_CONFIG_DEBUG_VERBOSE, "No day number given!\n", strlen("No day number given!\n"));
		return;
	}

	// check value
	int32_t day = atoi(token_buffer[1]);
	if(day > 25 || day <= 0)
	{
		AdventOfCode_print(AOC_CONFIG_DEBUG_VERBOSE, "Invalid day number given!\n", strlen("Invalid day number given!\n"));
		return;
	}

	// check implementation
	char buffer[1024];
	sprintf(buffer, "Executing release day %ld\n", day);
	AdventOfCode_print(AOC_CONFIG_DEBUG_VERBOSE, buffer, strlen(buffer));

	// check implementationday
	AdventOfCode_return_t ret = aoc.aoc_func_list[day - 1](AOC_CONFIG_TEST);
	if(ret != AOC_RETURN_OK)
	{
		AdventOfCode_print(AOC_CONFIG_DEBUG_VERBOSE, "\tState: Not implemented\n", strlen("\tState: Not implemented\n"));
		return;
	}

	// check debug file
	FILINFO fno;
	sprintf(buffer, "day%ld.txt", day);
	if(f_stat(buffer, &fno) != FR_OK)
	{
		AdventOfCode_print(AOC_CONFIG_DEBUG_VERBOSE, "\tRelease: Absent\n", strlen("\tRelease: Absent\n"));
		return;
	}


	// split line
	AdventOfCode_print(AOC_CONFIG_DEBUG_VERBOSE, "Start:\n", strlen("Start:\n"));

	// execute debug mode day
	uint32_t start = HAL_GetTick();
	AdventOfCode_return_t dret = aoc.aoc_func_list[day - 1](AOC_CONFIG_RELEASE_VERBOSE);
	uint32_t end = HAL_GetTick();

	// clear allocated memory
	sram_clrmem();

	// print execution results
	if(dret == AOC_RETURN_OK)
	{
		sprintf(buffer, "Succesfull: %ld ms\n", end - start);
		AdventOfCode_print(AOC_CONFIG_DEBUG_VERBOSE, buffer, strlen(buffer));
	}
	else
	{
		sprintf(buffer, "Failed: %ld ms\n", end - start);
		AdventOfCode_print(AOC_CONFIG_DEBUG_VERBOSE, buffer, strlen(buffer));
	}
}

static void fetchPuzzleInput(char token_buffer[6][32])
{
	// no value given
	if(token_buffer[1][0] == 0x00)
	{
		AdventOfCode_print(AOC_CONFIG_DEBUG_VERBOSE, "No file name given!\n", strlen("No file name given!\n"));
		return;
	}

	// check implementation
	char buffer[1028];
	sprintf(buffer, "Creating %s\n", token_buffer[1]);
	AdventOfCode_print(AOC_CONFIG_DEBUG_VERBOSE, buffer, strlen(buffer));

	// create file
	FIL file;
	uint8_t ret = f_open(&file, token_buffer[1], FA_CREATE_ALWAYS | FA_WRITE);
	if(ret != FR_OK)
	{
		AdventOfCode_print(AOC_CONFIG_DEBUG_VERBOSE, "Failed to create file!\n", strlen("Failed to create file!\n"));
		return;
	}

	// fetch data
	AdventOfCode_print(AOC_CONFIG_DEBUG_VERBOSE, "Uploade data:\n{\n", strlen("Uploade data:\n{\n"));

	usb_rx_ready = 0;
	uint8_t done = 0;
	uint32_t counter = 0;
	while(!done)
	{
		// wait for new data
		if(!usb_rx_ready)
			continue;

		// flicker lightn light
		if((counter++ % 2) == 0)
			HAL_GPIO_TogglePin(LED1_GPIO_Port, LED1_Pin);

		// check last character
		char last_character = usb_rx_buffer[usb_rx_length - 3];
		if(last_character == '`')
		{
			usb_rx_buffer[usb_rx_length - 3] = 0x00;
			done = 1;
		}

		// echo message
		sprintf(buffer, "%s", (char*)usb_rx_buffer);
		AdventOfCode_print(AOC_CONFIG_DEBUG_VERBOSE, buffer, strlen(buffer));

		// write to file
		f_write(&file, usb_rx_buffer, usb_rx_length, NULL);

		// clear flag
		usb_rx_ready = 0;
	}

	// close file
	f_close(&file);
	AdventOfCode_print(AOC_CONFIG_DEBUG_VERBOSE, "\n}\nSaving input\n", strlen("\n}\nSaving input\n"));

	// turn on light
	HAL_GPIO_WritePin(LED1_GPIO_Port, LED1_Pin, GPIO_PIN_SET);
}

static void showDirectory()
{
	// opening log
	AdventOfCode_print(AOC_CONFIG_DEBUG_VERBOSE, "Uploaded files:\n{\n", strlen("Uploaded files:\n{\n"));
	char buffer[64];

	DIR dir;
	FILINFO fno;
	uint8_t counter = 0;
	f_opendir(&dir, "/");
	do
	{
		f_readdir(&dir, &fno);
		if(fno.fname[0] != 0 && counter++ > 1)
		{
			sprintf(buffer, "\t%s\n", fno.fname);
			AdventOfCode_print(AOC_CONFIG_DEBUG_VERBOSE, buffer, strlen(buffer));
		}
	} while(fno.fname[0] != 0);
	f_closedir(&dir);

	// closing log
	AdventOfCode_print(AOC_CONFIG_DEBUG_VERBOSE, "}\n", strlen("}\n"));
}

static void deleteFile(char token_buffer[6][32])
{
	// no value given
	if(token_buffer[1][0] == 0x00)
	{
		AdventOfCode_print(AOC_CONFIG_DEBUG_VERBOSE, "No file name given!\n", strlen("No file name given!\n"));
		return;
	}

	// check implementation
	char buffer[1028];
	sprintf(buffer, "Deleting %s\n", token_buffer[1]);
	AdventOfCode_print(AOC_CONFIG_DEBUG_VERBOSE, buffer, strlen(buffer));

	// delete file
	uint8_t ret = f_unlink(token_buffer[1]);
	if(ret != FR_OK)
	{
		AdventOfCode_print(AOC_CONFIG_DEBUG_VERBOSE, "Failed to delete file!\n", strlen("Failed to delete file!\n"));
		return;
	}

	// deleted file
	AdventOfCode_print(AOC_CONFIG_DEBUG_VERBOSE, "Deleted file\n", strlen("Deleted file\n"));
}

static void showHelp()
{
	// print execution commands
	char puzzle_commands[] =
			"Puzzle execution commands:\n"
			"    check    > Check status of puzzle implementation and\n"
			"               pressence of puzzle input.\n"
			"               [check <day_number>]\n"
			"    test     > Run puzzle implementation using test input.\n"
			"               [test <day_number>]\n"
			"    release  > Run puzzle implementation using release input.\n"
			"               [release <day_number>]\n";
	AdventOfCode_print(AOC_CONFIG_DEBUG_VERBOSE, puzzle_commands, strlen(puzzle_commands));

	// print file commands
	char file_commands[] =
			"File management commands:\n"
			"    list     > List all puzzle input files on the SD card.\n"
			"               [list]\n"
			"    upload   > Upload puzzle input data to the SD card.\n"
			"               [upload <name_of_file>.txt]\n"
			"    delete   > Delete puzzle input data on the SD card.\n"
			"               [delete <name_of_file>.txt]\n";
	AdventOfCode_print(AOC_CONFIG_DEBUG_VERBOSE, file_commands, strlen(file_commands));
}

static void invalidCommand()
{
	char unknown_string[] = "Unkown command refer to the commands list using [help]!\n";
	AdventOfCode_print(AOC_CONFIG_DEBUG_VERBOSE, unknown_string, strlen(unknown_string));
}

void USBD_HandleCommands()
{
	// check if message is valid
	if(!usb_rx_ready)
		return;

	// turn on light
	HAL_GPIO_WritePin(LED1_GPIO_Port, LED1_Pin, GPIO_PIN_SET);

	// tokenize input
	char token_buffer[6][32];
	memset(token_buffer, 0x00, 6 * 32);
	char *token = strtok((char*)usb_rx_buffer, " ");
	uint8_t token_counter = 0;
	while(token != NULL && token_counter < 6)
	{
		memcpy(token_buffer[token_counter], token, strlen(token));
		token = strtok(NULL, " ");
		token_counter++;
	}

	// process command
	uint8_t token_length = strlen(token_buffer[0]);
	if(token_counter == 1) token_length -= 2;
	if(!memcmp(token_buffer[0], USB_COMMAND_CHECK, token_length))
		checkImplementation(token_buffer);
	else if(!memcmp(token_buffer[0], USB_COMMAND_TEST, token_length))
		runDebugImplementation(token_buffer);
	else if(!memcmp(token_buffer[0], USB_COMMAND_RELEASE, token_length))
		runReleaseImplementation(token_buffer);
	else if(!memcmp(token_buffer[0], USB_COMMAND_LIST, token_length))
		showDirectory();
	else if(!memcmp(token_buffer[0], USB_COMMAND_UPLOAD, token_length))
		fetchPuzzleInput(token_buffer);
	else if(!memcmp(token_buffer[0], USB_COMMAND_DELETE, token_length))
		deleteFile(token_buffer);
	else if(!memcmp(token_buffer[0], USB_COMMAND_HELP, token_length))
		showHelp();
	else
		invalidCommand();

	// print new cursor
	AdventOfCode_print(AOC_CONFIG_DEBUG_VERBOSE, ">", 1);

	// clear receive flag
	usb_rx_ready = 0;

	// turn off led
	HAL_GPIO_WritePin(LED1_GPIO_Port, LED1_Pin, GPIO_PIN_RESET);
}

/* USER CODE END 0 */

/**
  * @brief  The application entry point.
  * @retval int
  */
int main(void)
{
  /* MCU Configuration--------------------------------------------------------*/

  /* Reset of all peripherals, Initializes the Flash interface and the Systick. */
  HAL_Init();

  /* Configure the system clock */
  SystemClock_Config();

  /* Initialize all configured peripherals */
  MX_GPIO_Init();
  MX_DMA_Init();
  MX_SDMMC1_SD_Init();
  MX_USB_DEVICE_Init();
  MX_USB_HOST_Init();
  MX_USART1_UART_Init();
  MX_TIM1_Init();
  MX_TIM11_Init();
  MX_ADC1_Init();
  MX_FMC_Init();
  MX_FATFS_Init();
  /* USER CODE BEGIN 2 */

	// wait for usb connection
	while(!usb_connected)
		HAL_Delay(500);

	// system startup
	System_init(&system_state);

	// system init terminal log
	System_initLog(&system_state);
	System_selfTestLog(&system_state);

	// init AOC
	AdventOfCode_init(&aoc,
			AoC_Day_01,	AoC_Day_02,	AoC_Day_03,	AoC_Day_04,	AoC_Day_05,
			AoC_Day_06,	AoC_Day_07,	AoC_Day_08,	AoC_Day_09,	AoC_Day_10,
			AoC_Day_11,	AoC_Day_12,	AoC_Day_13,	AoC_Day_14,	AoC_Day_15,
			AoC_Day_16,	AoC_Day_17,	AoC_Day_18,	AoC_Day_19,	AoC_Day_20,
			AoC_Day_21,	AoC_Day_22,	AoC_Day_23,	AoC_Day_24,	AoC_Day_25);

  /* USER CODE END 2 */

  /* Infinite loop */
  /* USER CODE BEGIN WHILE */
	while (1)
	{
		USBD_HandleCommands();

    /* USER CODE END WHILE */
    MX_USB_HOST_Process();

    /* USER CODE BEGIN 3 */
	}
  /* USER CODE END 3 */
}

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


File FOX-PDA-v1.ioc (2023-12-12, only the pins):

Mcu.UserName=STM32F745IGKx
PA0/WKUP.Signal=ADCx_IN0
PA10.Signal=GPIO_Input
PA11.Signal=USB_OTG_FS_DM
PA12.Signal=USB_OTG_FS_DP
PA13.Signal=SYS_JTMS-SWDIO
PA14.Signal=SYS_JTCK-SWCLK
PA15.GPIO_Label=SDMMC_SW
PA15.Signal=GPIO_Input
PA2.Signal=ADCx_IN2
PA3.Signal=GPIO_Input
PA5.Signal=GPIO_Input
PA6.Signal=GPIO_Input
PA7.Signal=GPIO_Input
PA9.Signal=GPIO_Input
PB0.Signal=GPIO_Input
PB1.Signal=GPIO_Input
PB10.Signal=GPIO_Input
PB11.Signal=GPIO_Input
PB12.Signal=GPIO_Input
PB13.Signal=GPIO_Input
PB14.Signal=USB_OTG_HS_DM
PB15.Signal=USB_OTG_HS_DP
PB3.Signal=SYS_JTDO-SWO
PB4.Signal=GPIO_Input
PB5.Signal=GPIO_Input
PB6.GPIO_Label=WIFI_UART_TX
PB6.Signal=USART1_TX
PB7.GPIO_Label=WIFI_UART_RX
PB7.Signal=USART1_RX
PB8.GPIO_Label=WIFI_ENABLE
PB8.Signal=GPIO_Output
PC10.Signal=SDMMC1_D2
PC11.Signal=SDMMC1_D3
PC12.Signal=SDMMC1_CK
PC14/OSC32_IN.Signal=RCC_OSC32_IN
PC15/OSC32_OUT.Signal=RCC_OSC32_OUT
PC5.Signal=GPIO_Input
PC6.GPIO_Label=LED3
PC6.Signal=GPIO_Output
PC7.Signal=GPIO_Input
PC8.Signal=SDMMC1_D0
PC9.Signal=SDMMC1_D1
PD0.Signal=FMC_D2_DA2
PD1.Signal=FMC_D3_DA3
PD10.Signal=FMC_D15_DA15
PD11.Signal=FMC_A16_CLE
PD12.Signal=FMC_A17_ALE
PD13.Signal=FMC_A18
PD14.Signal=FMC_D0_DA0
PD15.Signal=FMC_D1_DA1
PD2.Signal=SDMMC1_CMD
PD4.Signal=FMC_NOE
PD5.Signal=FMC_NWE
PD6.Signal=GPIO_Input
PD7.Signal=FMC_NE1
PD8.Signal=FMC_D13_DA13
PD9.Signal=FMC_D14_DA14
PE0.Signal=FMC_NBL0
PE1.Signal=FMC_NBL1
PE10.Signal=FMC_D7_DA7
PE11.Signal=FMC_D8_DA8
PE12.Signal=FMC_D9_DA9
PE13.Signal=FMC_D10_DA10
PE14.Signal=FMC_D11_DA11
PE15.Signal=FMC_D12_DA12
PE3.Signal=FMC_A19
PE4.Signal=FMC_A20
PE5.Signal=FMC_A21
PE7.Signal=FMC_D4_DA4
PE8.Signal=FMC_D5_DA5
PE9.Signal=FMC_D6_DA6
PF0.Signal=FMC_A0
PF1.Signal=FMC_A1
PF11.Signal=GPIO_Input
PF12.Signal=FMC_A6
PF13.Signal=FMC_A7
PF14.Signal=FMC_A8
PF15.Signal=FMC_A9
PF2.Signal=FMC_A2
PF3.Signal=FMC_A3
PF4.Signal=FMC_A4
PF5.Signal=FMC_A5
PF7.GPIO_Label=STATUS_LED
PF7.Signal=S_TIM11_CH1
PG0.Signal=FMC_A10
PG1.Signal=FMC_A11
PG10.Signal=GPIO_Input
PG11.Signal=GPIO_Input
PG12.Signal=GPIO_Input
PG13.Signal=GPIO_Input
PG14.Signal=GPIO_Input
PG15.Signal=GPIO_Input
PG2.Signal=FMC_A12
PG3.Signal=FMC_A13
PG4.Signal=FMC_A14_BA0
PG5.Signal=FMC_A15_BA1
PG6.GPIO_Label=LED1
PG6.Signal=GPIO_Output
PG7.GPIO_Label=LED2
PG7.Signal=GPIO_Output
PG8.Signal=GPIO_Input
PH0/OSC_IN.Signal=RCC_OSC_IN
PH1/OSC_OUT.Signal=RCC_OSC_OUT
PI0.Signal=GPIO_Input
PI1.Signal=GPIO_Input
PI2.GPIO_Label=USB_HOST_VBUF
PI2.Signal=GPIO_Output
PI3.Signal=GPIO_Input

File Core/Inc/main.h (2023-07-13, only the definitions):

#define WIFI_ENABLE_Pin GPIO_PIN_8
#define WIFI_ENABLE_GPIO_Port GPIOB
#define SDMMC_SW_Pin GPIO_PIN_15
#define SDMMC_SW_GPIO_Port GPIOA
#define WIFI_UART_RX_Pin GPIO_PIN_7
#define WIFI_UART_RX_GPIO_Port GPIOB
#define WIFI_UART_TX_Pin GPIO_PIN_6
#define WIFI_UART_TX_GPIO_Port GPIOB
#define USB_HOST_VBUF_Pin GPIO_PIN_2
#define USB_HOST_VBUF_GPIO_Port GPIOI
#define LED3_Pin GPIO_PIN_6
#define LED3_GPIO_Port GPIOC
#define LED2_Pin GPIO_PIN_7
#define LED2_GPIO_Port GPIOG
#define LED1_Pin GPIO_PIN_6
#define LED1_GPIO_Port GPIOG
#define STATUS_LED_Pin GPIO_PIN_7
#define STATUS_LED_GPIO_Port GPIOF

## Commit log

2023-07-15 Added system check at startup with error handler implementation
    [main.c, main.h]
2024-03-12 Added hardware files
    [FOX-PDA-v1 BOM.xlsx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]

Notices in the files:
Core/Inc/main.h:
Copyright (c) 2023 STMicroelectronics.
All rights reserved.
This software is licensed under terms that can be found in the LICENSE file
